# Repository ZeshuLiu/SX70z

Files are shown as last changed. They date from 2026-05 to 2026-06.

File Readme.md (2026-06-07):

# SX-70z

## 介绍
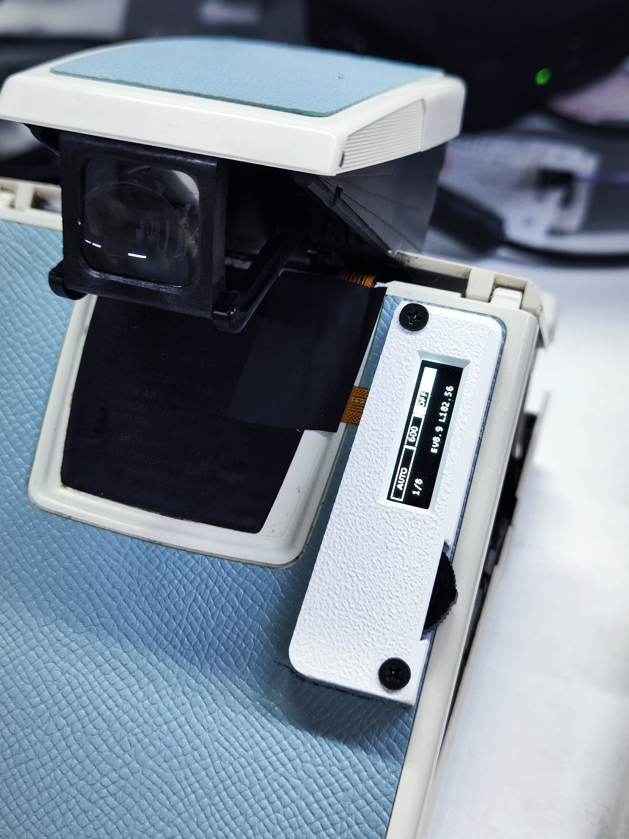
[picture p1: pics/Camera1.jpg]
机身照片


### 项目组成
项目中包含几个部分的硬件：

1. [相机主控板](Hardware/MainController)：替换相机机头内原装的控制器，接管相机的控制。
2. [机身控制器](Hardware/Body_controller)：显示当前相机工作状态并提供用于交互的按键。粘贴在机身背部，不会增加相机高度，因此大部分相机包依旧可以通用，与相机主控板连接需要 Fpc 排线。

### 开发

PCB部分除FPC使用嘉立创EDA外均使用KiCad9绘制，仓库提供了相应的工程和光绘(gerber)文件。

机身控制器采用ESP-IDF进行开发

## 性能参数
相机主控可以单独使用，此时可以进行自动测光和曝光，如果需要使用B、T以及手动模式需要配备机身控制器。

**快门速度：** 3s-1/8000s，共 27 档，支持 B 门及 T 门 。 T 门可设置时间，至多5h （非定时T和B门无时间限制）\
**自拍定时：** 0s/2s/5s/10s （倒计时完成后按当前模式自动曝光，倒计时期间挂起其余 Core 1 任务，不受按键干扰）\
**多重曝光：** 最多 11 张（受 MCU 机能限制，曝光过程中无法折叠相机，断电将导致快门保持打开状态造成严重过曝）。多重曝光期间电磁铁持续通电，间隔超过 5 分钟可能导致过热，建议尽快完成所有曝光并吐片。设置方式：长按进入设置菜单，切换 MultiExp 选项（-1 为仅中止/首张防护，0 为正常拍摄，1-10 为额外曝光张数）\
**测光：** 支持 ISO 640 相纸（通过 OPT4001 环境光传感器 + 窗口衰减系数 `METERING_ATTEN_K` 标定），实测与 **Sekonic L-308S** 测光表对比，全快门速度范围（3s – 1/8000s）精度一致，自动测光下最低快门速度 3s  \
**闪光同步：** 插入闪光灯后快门速度自动锁定 1/30s，手动模式可设置慢于 1/30s 进行填充闪光

*SX70的光圈在使用闪光灯时将会根据对焦距离进行收缩，此时调整黑白轮可以控制其光圈大小。本项目依旧保留了该特点，因此在使用闪光灯时请注意对焦距离以及黑白轮的位置*

### 曝光模式 × 闪光灯 行为矩阵

| 模式 | 无闪光灯 | 有闪光灯 |
|---|---|---|
| **AUTO** | 测光 → 自动选快门速度 → 普通曝光 | 快门固定 1/30s → 闪光曝光（47ms 预延迟后触发电容引闪） |
| **BULB** | 开快门 → 等 S1T 释放 → 关快门 | SOL2 光圈打开 → 开快门 → 47ms → 闪光 → 等 S1T 释放 |
| **TIME** | 开快门 → 等 S1T 按两次 → 关快门 | SOL2 光圈打开 → 开快门 → 47ms → 闪光 → 等 S1T 按两次 |
| **MANUAL** | 用户指定快门速度 → 普通曝光 | 快门限制在 1/30s，按用户速度计算 gap → 闪光曝光 |

所有模式下，相机任务均运行在 **ESP32 的 Core 1**，按优先级分层隔离，曝光时序不受 WiFi/BLE 干扰。

### 软件架构

```
Core 0:   WiFi 协议栈 + NimBLE BLE + HTTP Server (OTA Web) + 事件回调
Core 1:   相机控制（与射频中断隔离）
  ├─ Shutter  Task  prio 10 — 强时序引脚控制（busy-wait，独占 Core 1）
  ├─ Control  Task  prio 8  — 主控逻辑（按键/模式/S1 快门）
  ├─ Display  Task  prio 5  — SSD1306 I2C 刷屏（200ms 周期）
  └─ Metering Task  prio 3  — OPT4001 测光（1s 周期）
```

模块文件：

| 文件 | 职责 |
|---|---|
| `camera_main.c` | 任务调度、曝光时序、电磁铁/电机控制 |
| `gpio_inputs.c` | GPIO 输入处理：S1/S2 去抖、3D 按键、设置菜单（自拍定时 / 多重曝光 / IP 显示） |
| `display_manager.c` | OLED 帧绘制、倒计时显示、设置菜单布局 |
| `opt4001.c` | OPT4001 环境光传感器 I2C 驱动 |
| `ssd1306.c` | SSD1306 OLED I2C 驱动（esp_lcd 后端，含 `ssd1306_draw_str_black` 反色绘制） |
| `pcf8575.c` | PCF8575 I2C GPIO 扩展驱动 |
| `pin_init.c` | GPIO 引脚初始化 |
| `ota_web.c` | WiFi HTTP OTA 网页升级 |

### 设置菜单

长按 3D 按键的"按下"键进入设置菜单，菜单参数化支持上下键切换选项、短按"按下"键切换调整/浏览模式：

| 选项 | 说明 |
|---|---|
| **SelfTimer** | 自拍定时：0s / 2s / 5s / 10s |
| **MultiExp** | 多重曝光：-1（仅中止，首张防护）/ 0（正常）/ 1-10（额外张数，最多 11 张）|
| **IP Addr** | 只读，显示相机当前 WiFi IP 地址（未连接时显示 "not connected"）|

状态栏右上角同时显示当前自拍定时值与多重曝光剩余张数。

## 样片

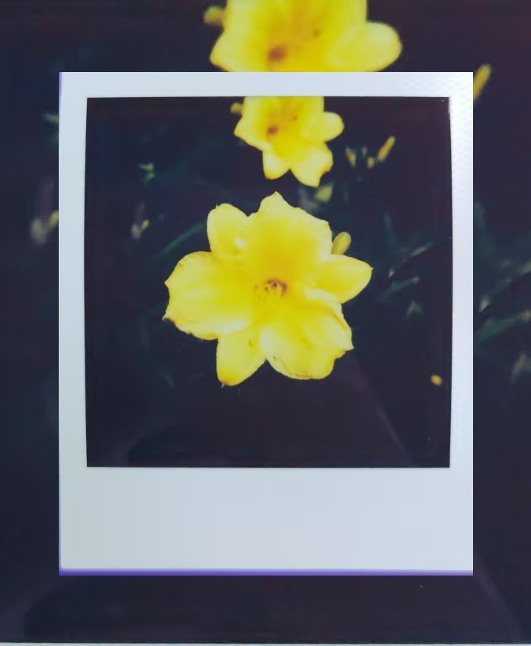
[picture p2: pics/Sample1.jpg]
样片1

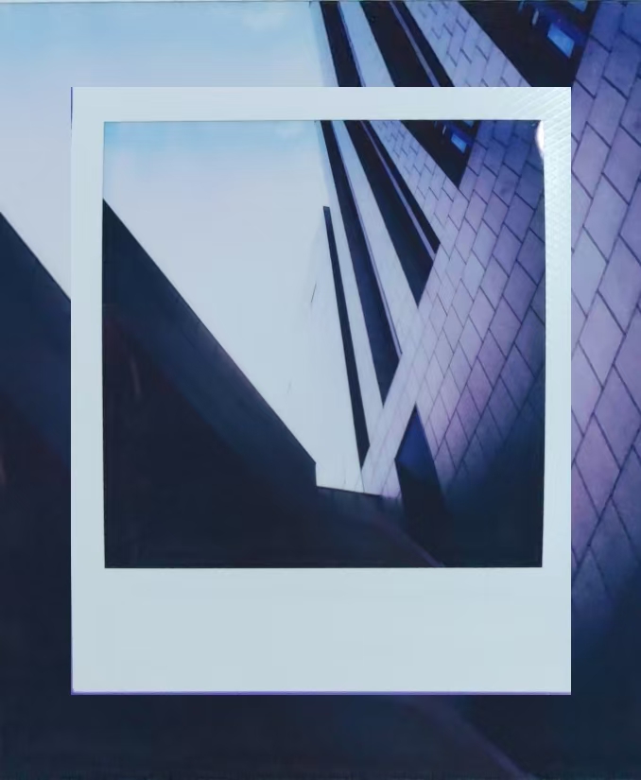
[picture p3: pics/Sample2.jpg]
样片2

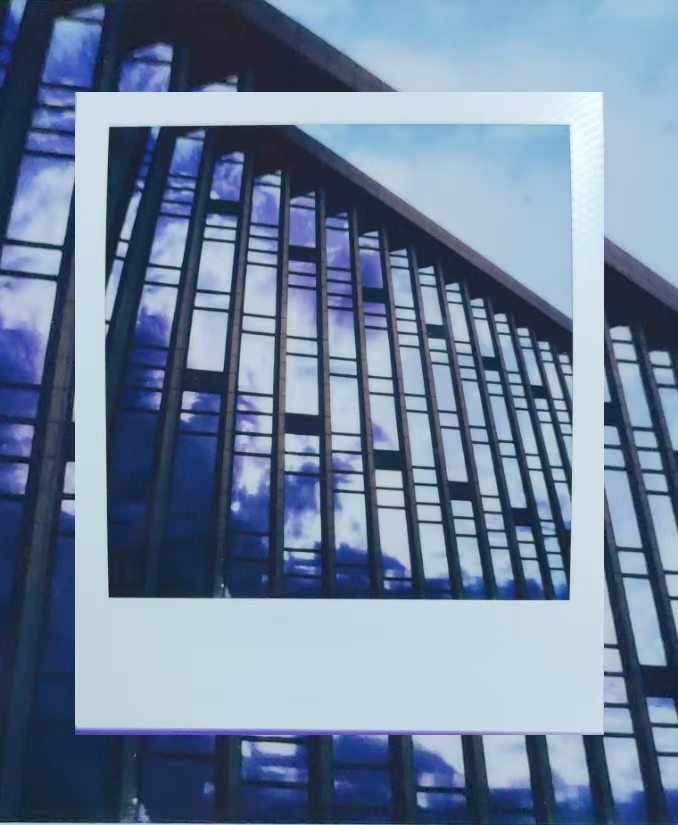
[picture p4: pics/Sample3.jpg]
样片3

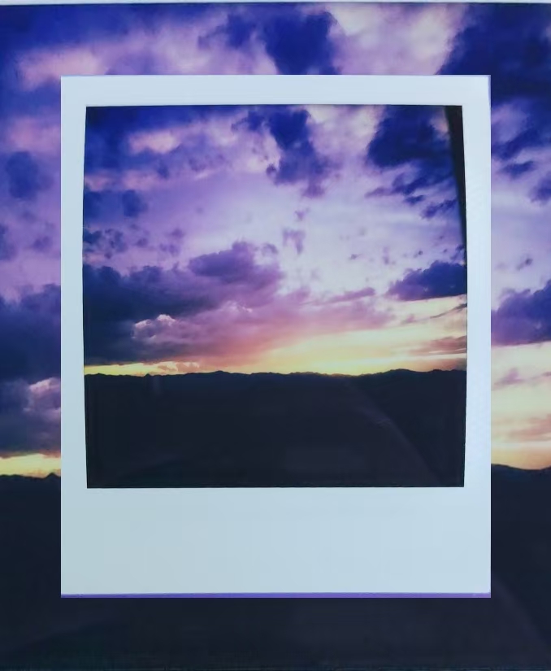
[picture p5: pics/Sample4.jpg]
样片4


## 硬件制造
光绘（Gerber）文件可以在 [Hardware](Hardware/) 目录下各子目录中找到，必须使用 0.8mm 以下的 PCB 制造。需要使用 fpc 软排线连接主板和机身控制器。

## 软件

在将机身主控安装至机器内部之前需要将固件通过串口烧录至控制器中。后续可以通过 OTA 无线升级，无需拆机。

**首次 WiFi 配网：**

首次开机相机没有 WiFi 凭据，会通过 BLE 广播 `SX70z_POP`。手机下载 **ESP BLE Provisioning** 应用（iOS/Android 应用商店均有），打开后选择配网，输入配对密钥 `sx70z123`，选择家中 WiFi 并输入密码即可。配网成功后凭据会存入 NVS，下次开机自动连接。

**OTA 升级方式：**
1. 相机开机连接 WiFi（通过 BLE 配网或已保存的凭据自动连接）
2. 手机或电脑连接同一局域网，浏览器打开 `http://SX70z` 或相机 IP
3. 选择编译好的 `.bin` 固件文件上传
4. 上传完成自动重启，新固件生效（Bootloader 会校验固件有效性，异常自动回滚）

建议针对自己的快门适当调整代码中 `shutter_times_x10[]` 的值，可以使用这个[快门速度测试器](https://github.com/ZeshuLiu/ShutterSpeedCalibrator)来测试机器的快门速度，便于调整。

## 组装
> 提示：组装需要一些基本的工具：电烙铁、撬棒和镊子。 \
大多数sx70相机的螺丝都是非常特殊的1mm x 1mm 宝丽来螺丝，拆卸需要特殊的螺丝刀，可以从咸鱼买一把或者自己磨一个。 \
在操作之前推荐先浏览以下内容[Disassembly Guide](https://instantphotography.files.wordpress.com/2010/12/polaroid-sx-70-camera-repair-book.pdf) 或者 [SX70 camera 125ASA to 600ASA conversion](https://opensx70.com/tutorials/100-600-conversion/).

拆卸后对原本主板进行替换即可，如需要机身控制器则将左上角焊盘焊线引出即可通过转接板连接机身控制器。焊接FPC时建议使用含铅(低温)焊锡，否则有损伤机器FPC的风险。只需要将原本的拆掉并且替换上去即可，对于有焊接及机身拆装经验的人来说难度不高。

### 相关开源软件

1. 项目受到了[OPSX ](https://github.com/sunyitong/OPSX)和[openSX70](https://github.com/openSX70)的启发。

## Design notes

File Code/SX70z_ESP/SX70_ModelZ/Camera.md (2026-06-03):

# Camera 工作模式与曝光流程

## 菜单模式

| `menu` | 模式 | `cam_mode` 显示 | `shut_mode` | 快门速度来源 |
|---|---|---|---|---|
| 0 | AUTO | `"AUTO"` | `'1'` | 测光自动计算 (`auto_shutter_pos`) |
| 1 | BULB (B) | `"B"` | `'B'` | 忽略，S1T 释放结束曝光 |
| 2 | TIME (T) | `"T"` | `'T'` | 忽略，S1T 按两次结束曝光 |
| 3 | MANUAL (M) | 快门速度字符串 | `'1'` | 用户手动选择（上/下键） |
| 10 | SELF-TIMER | `"---"` | 不变 | 禁止拍摄（shutter_task 跳过） |

## 全局参数

```c
typedef struct {
    bool if_display;            // OLED 是否可用
    bool has_flash;             // 闪光灯是否接入（control_task 防抖检测）

    metering_state_t metering;  // 测光
    button_state_t button;      // 按键

    uint8_t menu;               // 菜单层级
    char cam_mode[8];           // 当前模式显示字符串
    char shut_mode;             // 快门模式：'1'=NORMAL, 'B'=BULB, 'T'=TIME
    uint8_t shutter_speed;      // 快门速度索引 (0-26)

    bool test_led_level;        // LED 测试电平
} camera_state_t;
```

### camera_state.shut_mode 语义变化

旧代码中 `shut_mode` 混合表示闪光/模式两种状态：

- `'0'` = 闪光灯曝光路径
- `'1'` = 普通曝光
- `'B'` = B 门
- `'T'` = T 门

新代码中 `shut_mode` **仅表示用户选择的拍摄模式**，闪光灯作为独立 `has_flash` 布尔值传递：

- `'1'` = NORMAL 曝光（AUTO 和 MANUAL 共用）
- `'B'` = B 门
- `'T'` = T 门

`shutter_task` 内通过 `use_flash = camera_state.has_flash` 判断是否执行闪光相关步骤。

## 行为矩阵

| 模式 | 无闪光灯 | 有闪光灯 |
|---|---|---|
| **AUTO** | 测光 → `auto_shutter_pos` → `mode='1'` 普通曝光 | 快门固定 index 13 (1/30s) → `mode='1'` + `use_flash` → 闪光曝光 |
| **BULB** | `mode='B'` → 开快门 → 15ms → 等 S1T 释放 → 关快门 | `mode='B'` + `use_flash` → 开快门 → 15ms+32ms → **触发闪光** → 等 S1T 释放 → 关快门 |
| **TIME** | `mode='T'` → 开快门 → 等 S1T 释放 → 等再次按下 → 关快门 | `mode='T'` + `use_flash` → 开快门 → 47ms → **触发闪光** → 等 S1T 释放 → 等再次按下 → 关快门 |
| **MANUAL** | `mode='1'` → 用户指定快门速度 → 普通曝光 | `mode='1'` + `use_flash` → 按用户速度计算 gap → 闪光曝光 |
| **SELF-TIMER** | shutter_task 跳过（不拍摄） | shutter_task 跳过（不拍摄） |

## shutter_task 曝光时序

```
shutter_task (prio 10) — 由 xTaskNotifyGive 触发，执行完后回到阻塞态

  ┌─ 1. 关闭快门 ───────────────────────────────────────┐
  │    SOL1 100% 吸合 (30ms) → 40% 保持                  │
  ├─ 2. 电机启动，反光板上升 ──────────────────────────────┤
  │    电机转 → 等 S3 变高（反光板就位）→ 电机停           │
  ├─ 3. Y Delay ─────────────────────────────────────────┤
  │    if has_flash: SOL2 吸合（光圈打开）                 │
  │    固定 18ms Y 延时                                   │
  ├─ 4. 曝光（按 mode 分支） ──────────────────────────────┤
  │    mode='1' + 无闪光: 开快门 → gap 延时 → [步骤5关]   │
  │    mode='1' + 有闪光: 开快门 → 47ms → FF→1ms → gap   │
  │    mode='B':         开快门 → 15ms → [闪光] → 等释放  │
  │    mode='T':         开快门 → [闪光] → 等释放→等再按   │
  ├─ 5. 关闭快门 ────────────────────────────────────────┤
  │    SOL1 100% 吸合 (30ms) → 40% 保持 (18ms)           │
  ├─ 6. 光圈归位 ────────────────────────────────────────┤
  │    if has_flash: SOL2 断开                           │
  ├─ 7. 电机启动吐片 ─────────────────────────────────────┤
  │    电机转 → 等 S5 变低（胶片到位）→ 电机停 → SOL1释放  │
  └─ 8. 等 S1T 释放（防连拍） ────────────────────────────┘
```

### 普通曝光 (mode='1', 无闪光)

```
sol1_release()                     // 快门打开
delay_us(shutter_delay × 100)     // 按快门速度表延时（单位 0.1ms）
↓ 进入步骤 5
sol1_pull() → 30ms → sol1_hold()  // 快门关闭
```

### 闪光灯曝光 (mode='1', 有闪光)

```
sol1_release()                     // 快门打开
delay_us(47000)                    // 47ms — 等待快门完全打开
FF_PIN = 1  →  1ms  →  FF_PIN = 0 // 触发闪光灯
delay_us(gap × 100)               // 剩余延时
↓ 进入步骤 5
sol1_pull() → 30ms → sol1_hold()  // 快门关闭
```

其中 `gap = max(shutter_delay_x10 - 470, 0)`，闪光同步时总曝光时间 = 47ms + 1ms + gap。

### B 门 + 闪光

```
sol1_release()                     // 快门打开
delay_us(15000)                    // 15ms 稳定
delay_us(32000)                    // 额外 32ms，累计 47ms 后
FF_PIN = 1  →  1ms  →  FF_PIN = 0 // 触发闪光灯
while (S1T 释放)                   // 用户控制曝光时间
↓ 进入步骤 5 关快门
```

### T 门 + 闪光

```
sol1_release()                     // 快门打开
delay_us(47000)                    // 47ms
FF_PIN = 1  →  1ms  →  FF_PIN = 0 // 触发闪光灯
while (S1T 释放)                   // 第一次按下结束
while (S1T 再次按下)               // 第二次按下结束曝光
↓ 进入步骤 5 关快门
```

## 闪光灯检测

`control_task` 主循环中每 30ms 执行一次 S2 引脚防抖检测：

```c
// 闪光灯检测（带防抖）
static int flash_debounce = 0;
bool flash_level = (gpio_get_level(S2_PIN) == 0);
if (flash_level) {
    flash_debounce = min(flash_debounce + 1, 10);
} else {
    flash_debounce = max(flash_debounce - 1, 0);
}
camera_state.has_flash = (flash_debounce >= 8);
```

- S2 拉低 = 闪光灯接入
- 防抖阈值：连续检测到 8 次（~240ms）才确认有闪光灯
- 释放阈值：连续 2 次（~60ms 未检测到）开始递减

AUTO 模式下检测到闪光灯时，`shutter_speed` 被固定为 index 13（1/30s）：

```c
if (camera_state.menu == 0) {
    camera_state.shutter_speed = camera_state.metering.auto_shutter_pos;
    if (camera_state.has_flash) {
        camera_state.shutter_speed = 13;  // 1/30s
    }
}
```

## 快门速度表

27 档，索引 0~26：

| 索引 | 快门 | 标称 t(s) | EV | 阈值 EV | `shutter_times_x10` (0.1ms) |
|---|---|---|-----|---|---|
| 0 | 3s | 3.0 | 4.42 | ≤4.55 | 30000 |
| 1 | 2.5s | 2.5 | 4.68 | ≤4.84 | 25000 |
| 2 | 2s | 2.0 | 5.00 | ≤5.21 | 20000 |
| 3 | 1.5s | 1.5 | 5.42 | ≤5.71 | 15000 |
| 4 | 1s | 1.0 | 6.00 | ≤6.50 | 10500 |
| 5 | 1/2 | 0.5 | 7.00 | ≤7.29 | 5400 |
| 6 | 1/3 | 0.333 | 7.58 | ≤7.79 | 4700 |
| 7 | 1/4 | 0.25 | 8.00 | ≤8.29 | 3000 |
| 8 | 1/6 | 0.167 | 8.58 | ≤8.79 | 2900 |
| 9 | 1/8 | 0.125 | 9.00 | ≤9.16 | 1800 |
| 10 | 1/10 | 0.1 | 9.32 | ≤9.62 | 1450 |
| 11 | 1/15 | 0.0667 | 9.91 | ≤10.12 | 1060 |
| 12 | 1/20 | 0.05 | 10.32 | ≤10.62 | 880 |
| 13 | 1/30 | 0.0333 | 10.91 | ≤11.20 | 690 |
| 14 | 1/45 | 0.0222 | 11.49 | ≤11.70 | 610 |
| 15 | 1/60 | 0.0167 | 11.91 | ≤12.20 | 540 |
| 16 | 1/90 | 0.0111 | 12.49 | ≤12.73 | 500 |
| 17 | 1/125 | 0.008 | 12.96 | ≤13.23 | 450 |
| 18 | 1/180 | 0.00556 | 13.49 | ≤13.73 | 430 |
| 19 | 1/250 | 0.004 | 13.96 | ≤14.23 | 410 |
| 20 | 1/360 | 0.00278 | 14.49 | ≤14.73 | 370 |
| 21 | 1/500 | 0.002 | 14.96 | ≤15.46 | 340 |
| 22 | 1/1000 | 0.001 | 15.96 | ≤16.46 | 320 |
| 23 | 1/2000 | 0.0005 | 16.96 | ≤17.46 | 300 |
| 24 | 1/4000A | 0.00025 | 17.96 | ≤18.46 | 280 |
| 25 | 1/4000B | 0.00025 | 17.96 | (手动) | 260 |
| 26 | 1/8000 | 0.000125 | 18.96 | —— | 240 |

- `shutter_times_x10` 是光学校准后的实际延时值，单位 0.1ms
- EV 基于 F/8 镜头：`EV = log₂(64 / t_nominal)`
- `calc_shutter_from_ev(ev)` 用阈值 EV 查表，返回索引

## OLED 显示布局

```
┌──────────────────────────────────────────────┐
│ SX70z          B        EV13.6 L430.12       │
│ 3s     OFF     FLASH                          │
├──────────────────────────────────────────────┤
│ 上排左: 快门速度大字    上排右: EV / LUX      │
│ 下排左: 闪光灯状态      下排中: 拍摄模式       │
│         (OFF/FLASH)          (AUTO/B/T/speed) │
└──────────────────────────────────────────────┘
```

- `has_flash=false` → 显示 `"OFF"`
- `has_flash=true`  → 显示 `"FLASH"`
- `cam_mode` 在 AUTO 模式实时反映测光结果
- `menu=3`(MANUAL) 时 `cam_mode` 显示当前选择的快门速度字符串

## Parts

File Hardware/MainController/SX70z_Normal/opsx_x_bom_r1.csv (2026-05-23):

ID | 指示符 | 封装 | 数量 | 名称 | 供应商和参考
1 | U4 | TMB6-1.55-3.8X2.6MM | 1 | OPTICAL-TSL2561T(6P-3.8X2.6MM)
2 | U2 | DBV0005A_N | 1 | TLV70430DBVR
3 | R35,R27,R26,R3 | R_0402_1005Metric_Pad0.72x0.64mm_HandSolder | 4 | 1k
4 | D6,D5 | D_0603_1608Metric_Pad1.05x0.95mm_HandSolder | 2 | LED
5 | R34 | R_0402_1005Metric_Pad0.72x0.64mm_HandSolder | 1 | 330
6 | Q3 | SOT-23 | 1 | Q_PMOS_GSD
7 | R33 | R_0402_1005Metric_Pad0.72x0.64mm_HandSolder | 1 | 2.7k
8 | R32 | R_0402_1005Metric_Pad0.72x0.64mm_HandSolder | 1 | 47k
9 | R31 | R_0402_1005Metric_Pad0.72x0.64mm_HandSolder | 1 | 5.6k
10 | Q4 | SOT-23 | 1 | MMBT3904
11 | Z3,Z2,Z1 | Selector_default | 3 | ~
12 | R30 | R_0402_1005Metric_Pad0.72x0.64mm_HandSolder | 1 | 150
13 | R29 | R_0402_1005Metric_Pad0.72x0.64mm_HandSolder | 1 | 180
14 | C15 | C_0402_1005Metric_Pad0.74x0.62mm_HandSolder | 1 | 13p
15 | U6,U5 | TSOT-23-5 | 2 | AD8603
16 | R28,R8,R25,R23 | R_0402_1005Metric_Pad0.72x0.64mm_HandSolder | 4 | 100k
17 | R7 | R_0805_2012Metric_Pad1.20x1.40mm_HandSolder | 1 | 22k
18 | R10,R16,R14,R18,R5,R20 | R_0402_1005Metric_Pad0.72x0.64mm_HandSolder | 6 | 12k
19 | C8,C14,C6,C2,C10,C12,C7,C1,C9,C11 | C_0402_1005Metric_Pad0.74x0.62mm_HandSolder | 10 | 100n
20 | R12,R15,R6,R19,R9,R17,R11,R4,R13 | R_0402_1005Metric_Pad0.72x0.64mm_HandSolder | 9 | 10k
21 | R1,R2 | R_0402_1005Metric_Pad0.72x0.64mm_HandSolder | 2 | 27.4
22 | Q2,Q1 | SOT-23 | 2 | Q_NMOS_GSD
23 | sx1 | sx70 | 1 | sx~
24 | J2,J1,J3 | PinHeader_1x02_P2.54mm_Vertical | 3 | Conn_01x02
25 | C4 | C_0402_1005Metric_Pad0.74x0.62mm_HandSolder | 1 | 0.1u
26 | Y1 | Resonator_SMD_Murata_CSTxExxV-3Pin_3.0x1.1mm | 1 | Crystal_GND2
27 | D4,D3,D1 | D_SOD-323 | 3 | 1N4148WS
28 | R24,R21,R22 | R_0402_1005Metric_Pad0.72x0.64mm_HandSolder | 3 | 100
29 | U3 | SOIC-8_5.23x5.23mm_P1.27mm | 1 | W25Q128JVS
30 | C3,C13,C5 | C_0402_1005Metric_Pad0.74x0.62mm_HandSolder | 3 | 1u
31 | U1 | RP2040-QFN-56 | 1 | RP2040
32 | D2 | Osram_SFH2430 | 1 | SFH2430

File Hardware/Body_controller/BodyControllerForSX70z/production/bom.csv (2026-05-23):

Designator | Footprint | Quantity | Value | LCSC Part #
C1, C10, C11, C12, C2, C5, C6 | 0603 | 7 | 1uF
C3 | 0603 | 1 | 2.2uF
C4 | 0603 | 1 | 4.7uF
C7 | 0603 | 1 | 1uF(4.7uF)
DISP1 | SSD1306_0.91_i2c | 1 | ~
J1 | FPC-0.5LX-12PH20 | 1 | FPC-0.5LX-12PH20
J2 | PinHeader_1x04_P2.54mm_Horizontal | 1 | Conn_01x04_Pin
R1 | 0603 | 1 | 390k
R11, R3, R4 | 0603 | 3 | 10k
R2 | 0603 | 1 | 4.7k
SW3 | Direction3 Pin5 | 1 | ~
U1 | SSOP-20_4.4x6.5mm_P0.65mm | 1 | PCF8574ATS

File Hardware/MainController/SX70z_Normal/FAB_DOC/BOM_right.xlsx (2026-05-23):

Comment | Designator | Footprint | 嘉立创元件编号
100nF | C1,C2,C4,C6,C7,C8,C9,C10,C11,C12,C14 | 0402_C | C307331
1uF | C3,C5,C13 | 0402_C | C52923
1N4148WS | D1,D3,D4 | D_SOD-323 | C2128
LED | D5 | 0603_D | C72041
LED | D6 | 0603_D | C72038
Q_NMOS_GSD | Q1,Q2 | SOT-23 | C23521
Q_PMOS_GSD | Q3 | SOT-23 | C8549
MMBT3904 | Q4 | SOT-23 | C20526
27.4Ω | R1,R2 | 0402_R | C102945
1kΩ | R26,R27 | 0402_R | C11702
10kΩ | R4,R6,R9,R11,R12,R13,R15,R17,R19 | 0402_R | C25744
12kΩ | R5,R10,R14,R16,R18,R20 | 0402_R | C25752
100kΩ | R8,R28 | 0402_R | C25741
120Ω | R21,R22,R24 | 0402_R | C25079
5.6kΩ | R31 | 0402_R | C25908
47kΩ | R32 | 0402_R | C25792
2.7kΩ | R33 | 0402_R | C352444
330Ω | R34 | 0402_R | C25104
RP2040 | U1 | LQFN-56(7x7) | C2040
TLV70430DBVR | U2 | SOT-23-5 | C133625
W25Q128JVS | U3 | SOIC-8_5.23x5.23mm_P1.27mm | C97521
Crystal_GND2 | Y1 | Resonator_SMD_Murata_CSTxExxV-3Pin_3.0x1.1mm | C91581
1kΩ | R3,R35 | 0402_R | C11702
100kΩ | R23,R25 | 0402_R | C25741

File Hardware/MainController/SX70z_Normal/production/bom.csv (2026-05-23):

Designator | Footprint | Quantity | Value | LCSC Part #
C1, C2, C3 | 402 | 3 | DNP
C15, C6 | 402 | 2 | 100n
C4, C5 | 402 | 2 | 1u
C7 | 402 | 1 | 10uf
D1, D3, D4 | D_SOD-323 | 3 | 1N4148WS
D5 | 603 | 1 | LED
J1, J3 | PinHeader_1x02_P2.54mm_Vertical | 2 | Conn_01x02
J2 | PinHeader_1x03_P2.54mm_Vertical | 1 | Conn_01x03_Socket
L1 | 402 | 1 | 0R
Q1, Q2 | SOT-23 | 2 | Q_NMOS_GSD
Q5 | SOT-23 | 1 | MMBT3904
Q6 | SOT-23 | 1 | Q_PMOS_GSD
R1, R4, R11, R12, R13, R17, R19, R2, R3, R5, R9 | 402 | 10 | 10k
R10, R14, R18, R20 | 402 | 4 | 12k
R21, R22, R24 | 402 | 3 | 120
R23, R25 | 402 | 2 | 100k
R26 | 402 | 1 | 2.7k
R34 | 402 | 2 | 330
R6 | 402 | 1 | 1k
R7 | 402 | 1 | 5.6k
R8 | 402 | 1 | 47k
SX1 | sx70_i2c | 1 | sx~
U1 | AN2051-245 | 1 | ~
U3 | SOT-23-5 | 1 | SPX3819M5-L-3-3
U4 | QFN-48-1EP_7x7mm_P0.5mm_EP5.1x5.1mm_ThermalVias | 1 | ESP32-PICO-D4
U5 | OPT4001-DTS0008A-MFG | 1 | OPT4001DTSR

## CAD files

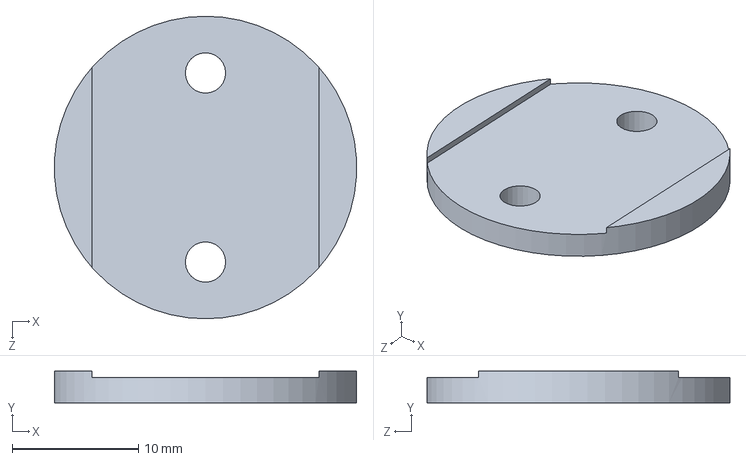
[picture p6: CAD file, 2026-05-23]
Hardware/TestBench/MainStandCover.SLDPRT
24.0 x 2.50 x 24.0 mm

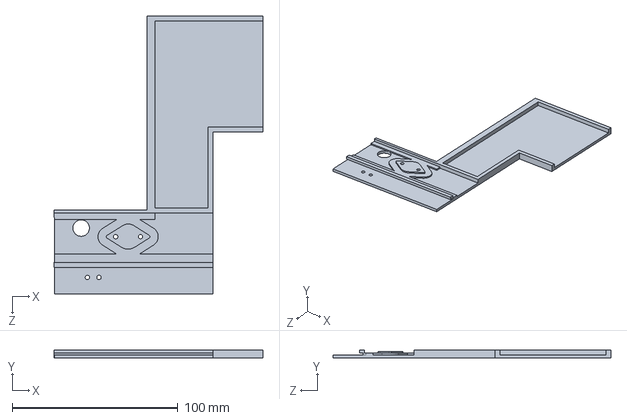
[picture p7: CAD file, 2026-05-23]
Hardware/TestBench/MainStand.SLDPRT
125.9 x 5.00 x 167.8 mm

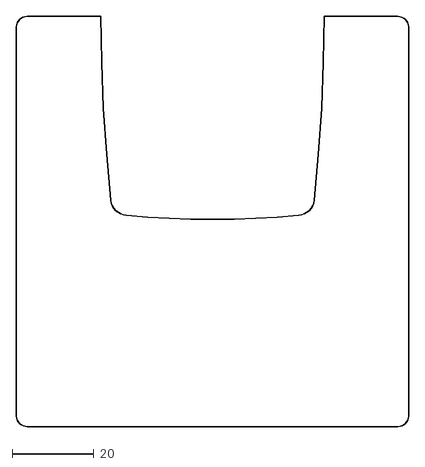
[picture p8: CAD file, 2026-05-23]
Hardware/Body_controller/BodyControllerForSX70z/sx-70-skin-back.dxf
96.1 x 100.6

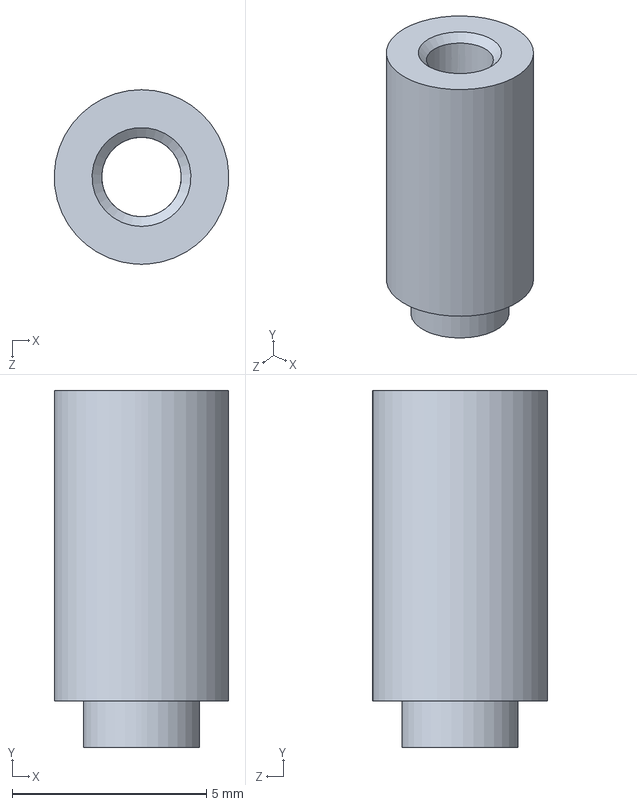
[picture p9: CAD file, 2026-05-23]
Hardware/Body_controller/Case/贴片螺母M2.5-H8-D3.SLDPRT
4.50 x 9.20 x 4.50 mm

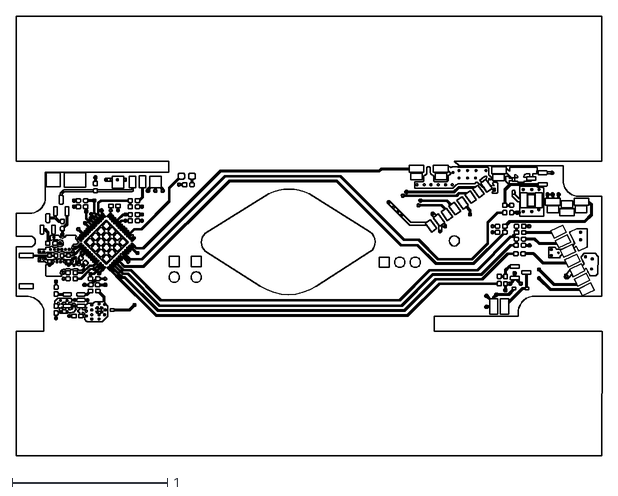
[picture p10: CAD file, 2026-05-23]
Hardware/MainController/SX70z_Normal/DXFs/SX70z_Normal-F_Cu.dxf
3.78 x 2.83

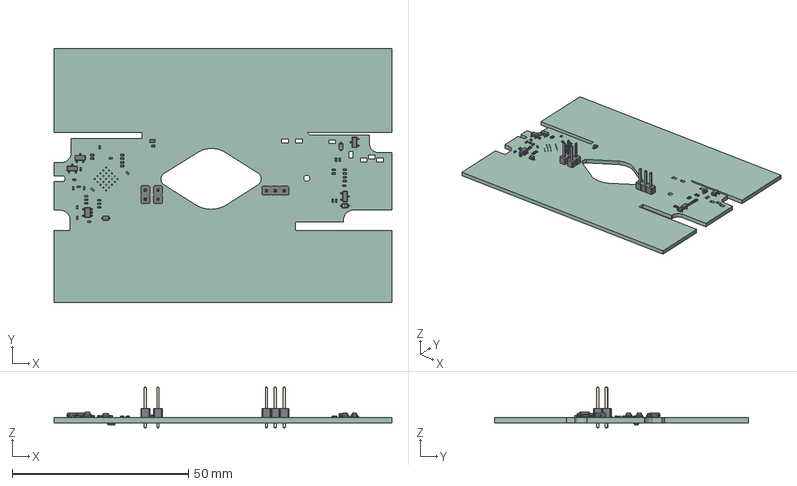
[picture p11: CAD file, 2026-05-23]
Hardware/MainController/SX70z_Normal/SX70z_Normal.step
95.9 x 72.0 x 11.5 mm
R_0402_1005Metric x 26
SOT-23 x 4
C_0402_1005Metric x 9
L_0402_1005Metric
D_SOD-323 x 3
D_0603_1608Metric
PinHeader_1x02_P2.54mm_Vertical x 2
PinHeader_1x03_P2.54mm_Vertical
SOT-23-5
FRAME
MOLD
SX70z_Normal_PCB

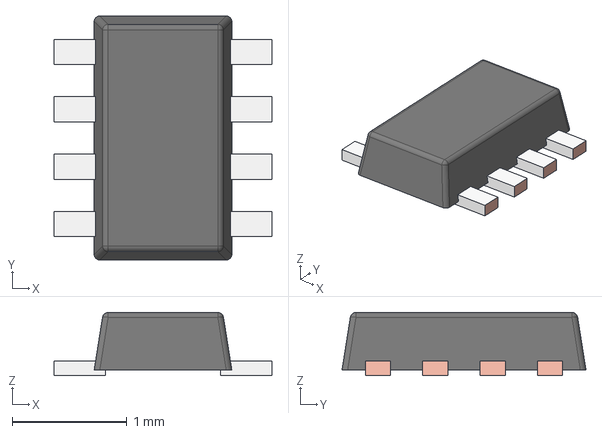
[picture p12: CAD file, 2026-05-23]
Hardware/MainController/SX70z_Normal/ul_OPT4001DTSR/OPT-4001-DTS0008A.stp
1.90 x 2.13 x 0.55 mm
FRAME
MOLD

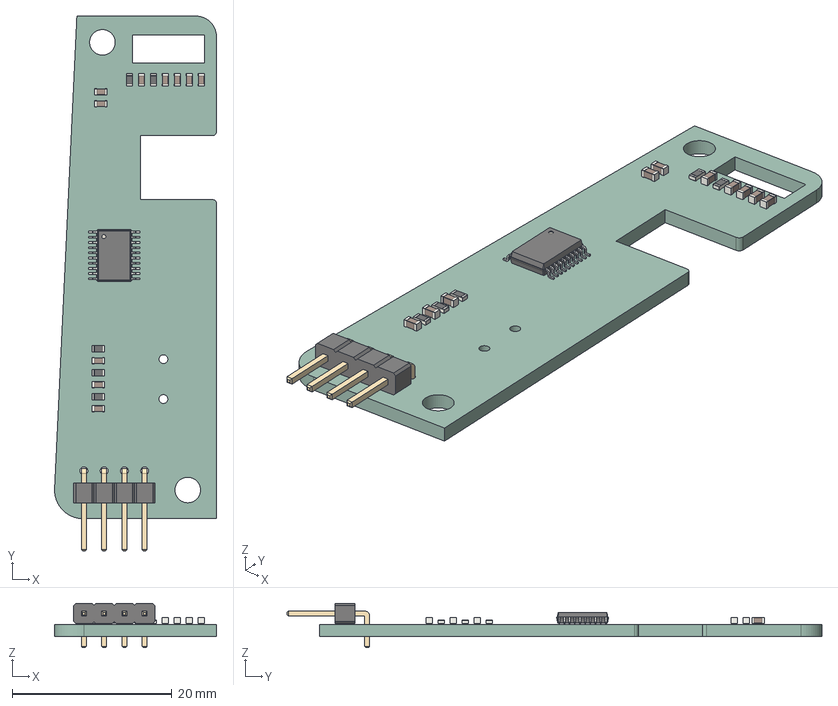
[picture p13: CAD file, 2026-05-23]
Hardware/Body_controller/BodyControllerForSX70z/BodyControllerForSX70z_R1_0.step
20.3 x 67.0 x 5.54 mm
C_0603_1608Metric x 10
R_0603_1608Metric x 5
PinHeader_1x04_P2.54mm_Horizontal
SSOP-20_4.4x6.5mm_P0.65mm
BodyControllerForSX70z_PCB

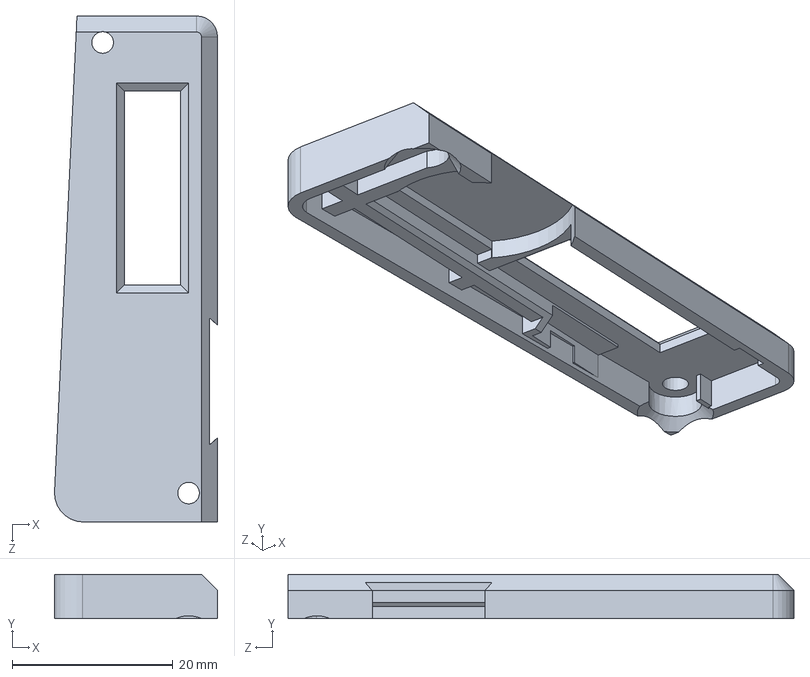
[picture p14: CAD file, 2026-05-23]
Hardware/Body_controller/Case/外壳.SLDPRT
20.3 x 5.50 x 63.0 mm

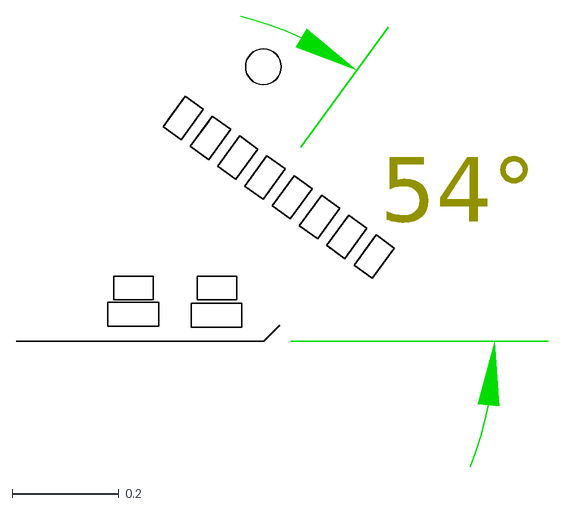
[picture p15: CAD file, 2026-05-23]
Hardware/MainController/SX70z_Normal/DXFs/SX70z_Normal_连接器部分外形.dxf
54°

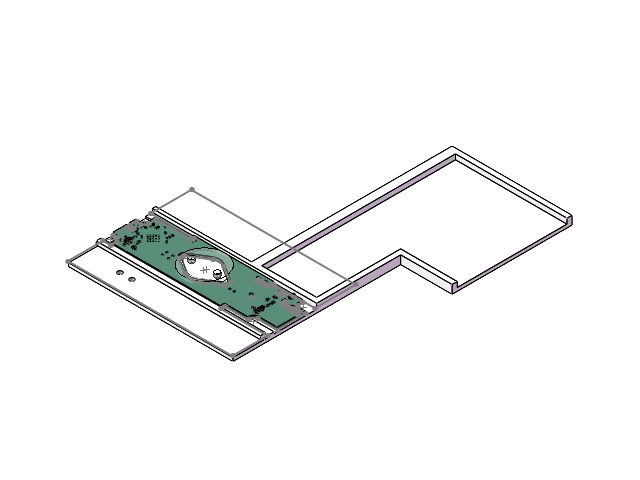
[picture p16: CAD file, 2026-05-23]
Hardware/TestBench/TestBench.SLDASM
MainStand
FRAME
MOLD
R_0402_1005Metric x 26
SOT-23 x 4
C_0402_1005Metric x 9
L_0402_1005Metric
D_SOD-323 x 3
D_0603_1608Metric
SOT-23-5
SX70z_Normal_PCB
MainStandCover

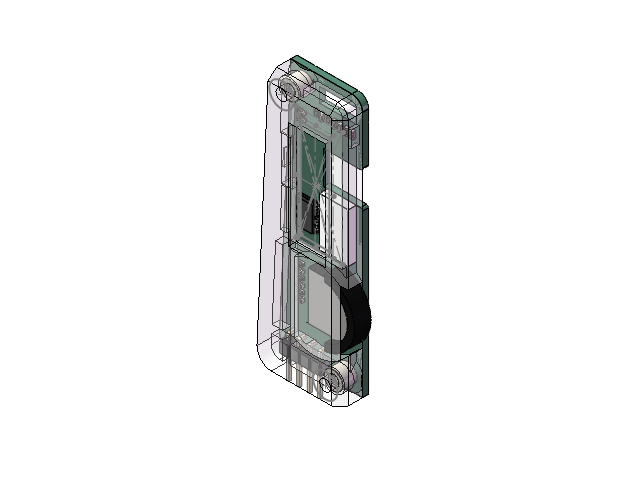
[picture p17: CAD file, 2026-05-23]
Hardware/Body_controller/Case/外壳装配.SLDASM
C_0603_1608Metric_2.step x 10
R_0603_1608Metric_2.step x 5
PinHeader_1x04_P2.54mm_Horizontal_2.step
SSOP-20_4.4x6.5mm_P0.65mm_2.step
BodyControllerForSX70z_PCB_2.step
贴片螺母M2.5-H3.5-D3 x 2
大头拨轮
外壳
垫片

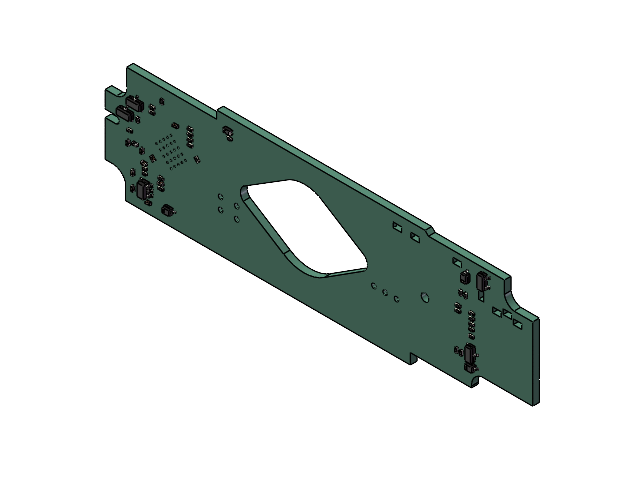
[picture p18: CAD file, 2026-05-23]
Hardware/TestBench/PCB/SX70z_Normal_R3_5.SLDASM
FRAME
MOLD
R_0402_1005Metric x 26
SOT-23 x 4
C_0402_1005Metric x 9
L_0402_1005Metric
D_SOD-323 x 3
D_0603_1608Metric
SOT-23-5
SX70z_Normal_PCB

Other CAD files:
Hardware/TestBench/PCB/SX70z_Normal.SLDASM
Hardware/TestBench/PCB/OPT-4001-DTS0008A.SLDASM
Hardware/Body_controller/ref/sx-70-skin-template-vector-v1.10-empty.dwg
Hardware/TestBench/PCB/SX70z_Normal_PCB.SLDPRT
Hardware/Body_controller/ref/sx-70-skin-sholder.dxf
Hardware/Body_controller/BodyControllerForSX70z/BodyControllerForSX70z_R1_1.step
Hardware/Body_controller/Case/BodyControllerForSX70z_R1_0.SLDASM
Hardware/Body_controller/Case/BodyControllerForSX70z_R1_1.SLDASM
Hardware/Body_controller/Case/BodyControllerForSX70z_R1_1.step
Hardware/Body_controller/Case/垫片.SLDPRT
Hardware/Body_controller/Case/垫片.STL
Hardware/Body_controller/Case/外壳.3mf
Hardware/Body_controller/Case/外壳.STL
Hardware/Body_controller/Case/大头拨轮.SLDPRT
Hardware/Body_controller/Case/贴片螺母M2.5-H3.5-D3.SLDPRT
Hardware/Body_controller/ref/sx-70-skin-sholder.dwg
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

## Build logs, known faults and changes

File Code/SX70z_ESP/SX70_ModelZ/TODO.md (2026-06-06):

# T、B门菜单合并
camera_state 加一个 uint16 TIME_MODE：0-B 1-T 然后再往上就是时间。统一归到menu 1里面去，通过上下键控制
然后这时候手动挡会变成menu 2

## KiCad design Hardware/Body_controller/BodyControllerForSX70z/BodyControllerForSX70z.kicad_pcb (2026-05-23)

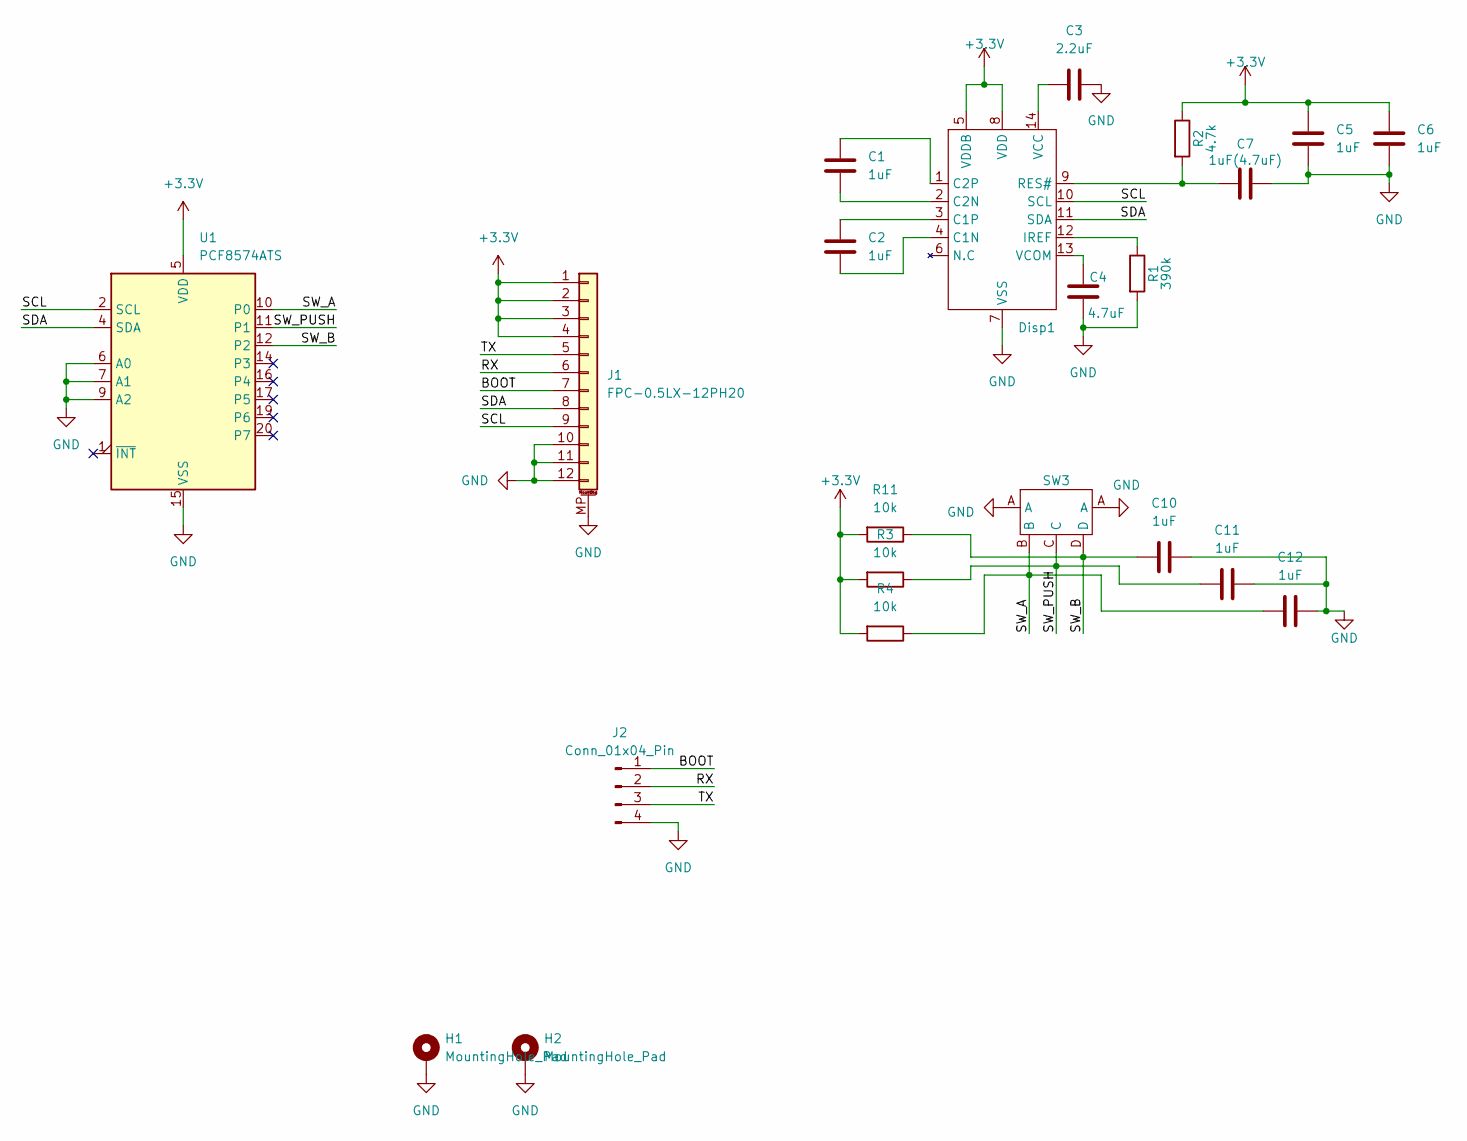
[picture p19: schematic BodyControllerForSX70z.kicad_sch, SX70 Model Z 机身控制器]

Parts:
C1, C2, C5, C6, C10, C11, C12: 1uF; C_0603_1608Metric_Pad1.08x0.95mm_HandSolder
C3: 2.2uF; C_0603_1608Metric_Pad1.08x0.95mm_HandSolder
C4: 4.7uF; C_0603_1608Metric_Pad1.08x0.95mm_HandSolder
C7: 1uF(4.7uF); C_0603_1608Metric_Pad1.08x0.95mm_HandSolder
Disp1: SSD1306_0.91_i2c
H1, H2: MountingHole_Pad; MountingHole_3.2mm_M3_DIN965_Pad
J1: FPC-0.5LX-12PH20
J2: Conn_01x04_Pin; PinHeader_1x04_P2.54mm_Horizontal
R1: 390k; R_0603_1608Metric_Pad0.98x0.95mm_HandSolder
R2: 4.7k; R_0603_1608Metric_Pad0.98x0.95mm_HandSolder
R3, R4, R11: 10k; R_0603_1608Metric_Pad0.98x0.95mm_HandSolder
SW3: Direction3 Pin5
U1: PCF8574ATS; SSOP-20_4.4x6.5mm_P0.65mm

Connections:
+3.3V: C5.1, C6.1, Disp1.5 (VDDB), Disp1.8 (VDD), J1.1, J1.2, J1.3, J1.4, R2.1, R3.2, R4.2, R11.2, U1.5 (VDD)
/BOOT: J1.7, J2.1
/RX: J1.6, J2.2
/SCL: Disp1.10 (SCL), J1.9, U1.2 (SCL)
/SDA: Disp1.11 (SDA), J1.8, U1.4 (SDA)
/SW_A: C12.1, R4.1, SW3.B, U1.10 (P0)
/SW_B: C10.1, R11.1, SW3.D, U1.12 (P2)
/SW_PUSH: C11.1, R3.1, SW3.C, U1.11 (P1)
/TX: J1.5, J2.3
GND: C3.2, C4.1, C5.2, C6.2, C7.2, C10.2, C11.2, C12.2, Disp1.7 (VSS), H1.1, H2.1, J1.10, J1.11, J1.12, J1.MP (MountPin), J2.4, R1.2, SW3.A, U1.6 (A0), U1.7 (A1), U1.9 (A2), U1.15 (VSS)
unnamed: C2.2, Disp1.4 (C1N)
unnamed: C2.1, Disp1.3 (C1P)
unnamed: C1.2, Disp1.2 (C2N)
unnamed: C1.1, Disp1.1 (C2P)
unnamed: Disp1.12 (IREF), R1.1
unnamed: C7.1, Disp1.9 (RES#), R2.2
unnamed: C3.1, Disp1.14 (VCC)
unnamed: C4.2, Disp1.13 (VCOM)

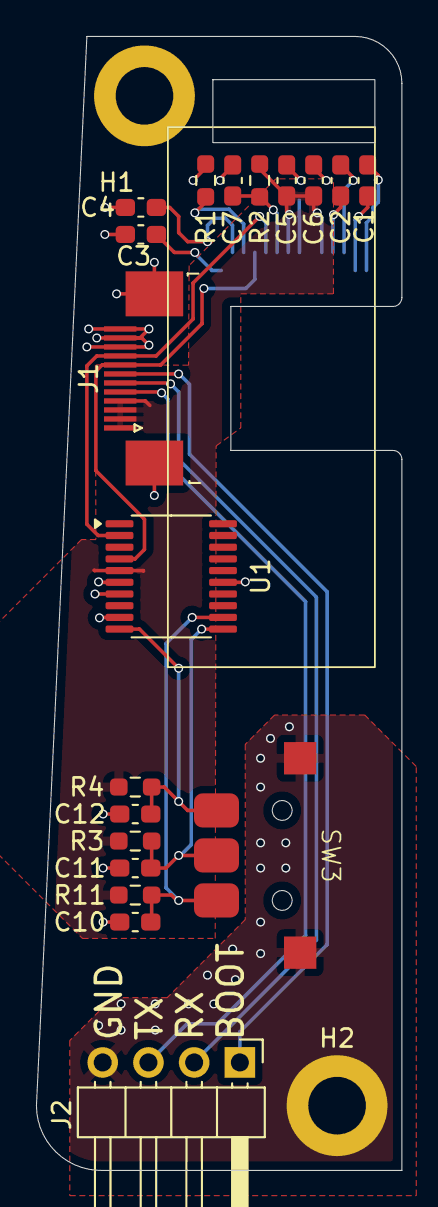
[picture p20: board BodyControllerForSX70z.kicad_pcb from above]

Board: 2 copper layers, 20.3 x 63.0 mm, 22 parts (1 on the bottom side), 18 nets.

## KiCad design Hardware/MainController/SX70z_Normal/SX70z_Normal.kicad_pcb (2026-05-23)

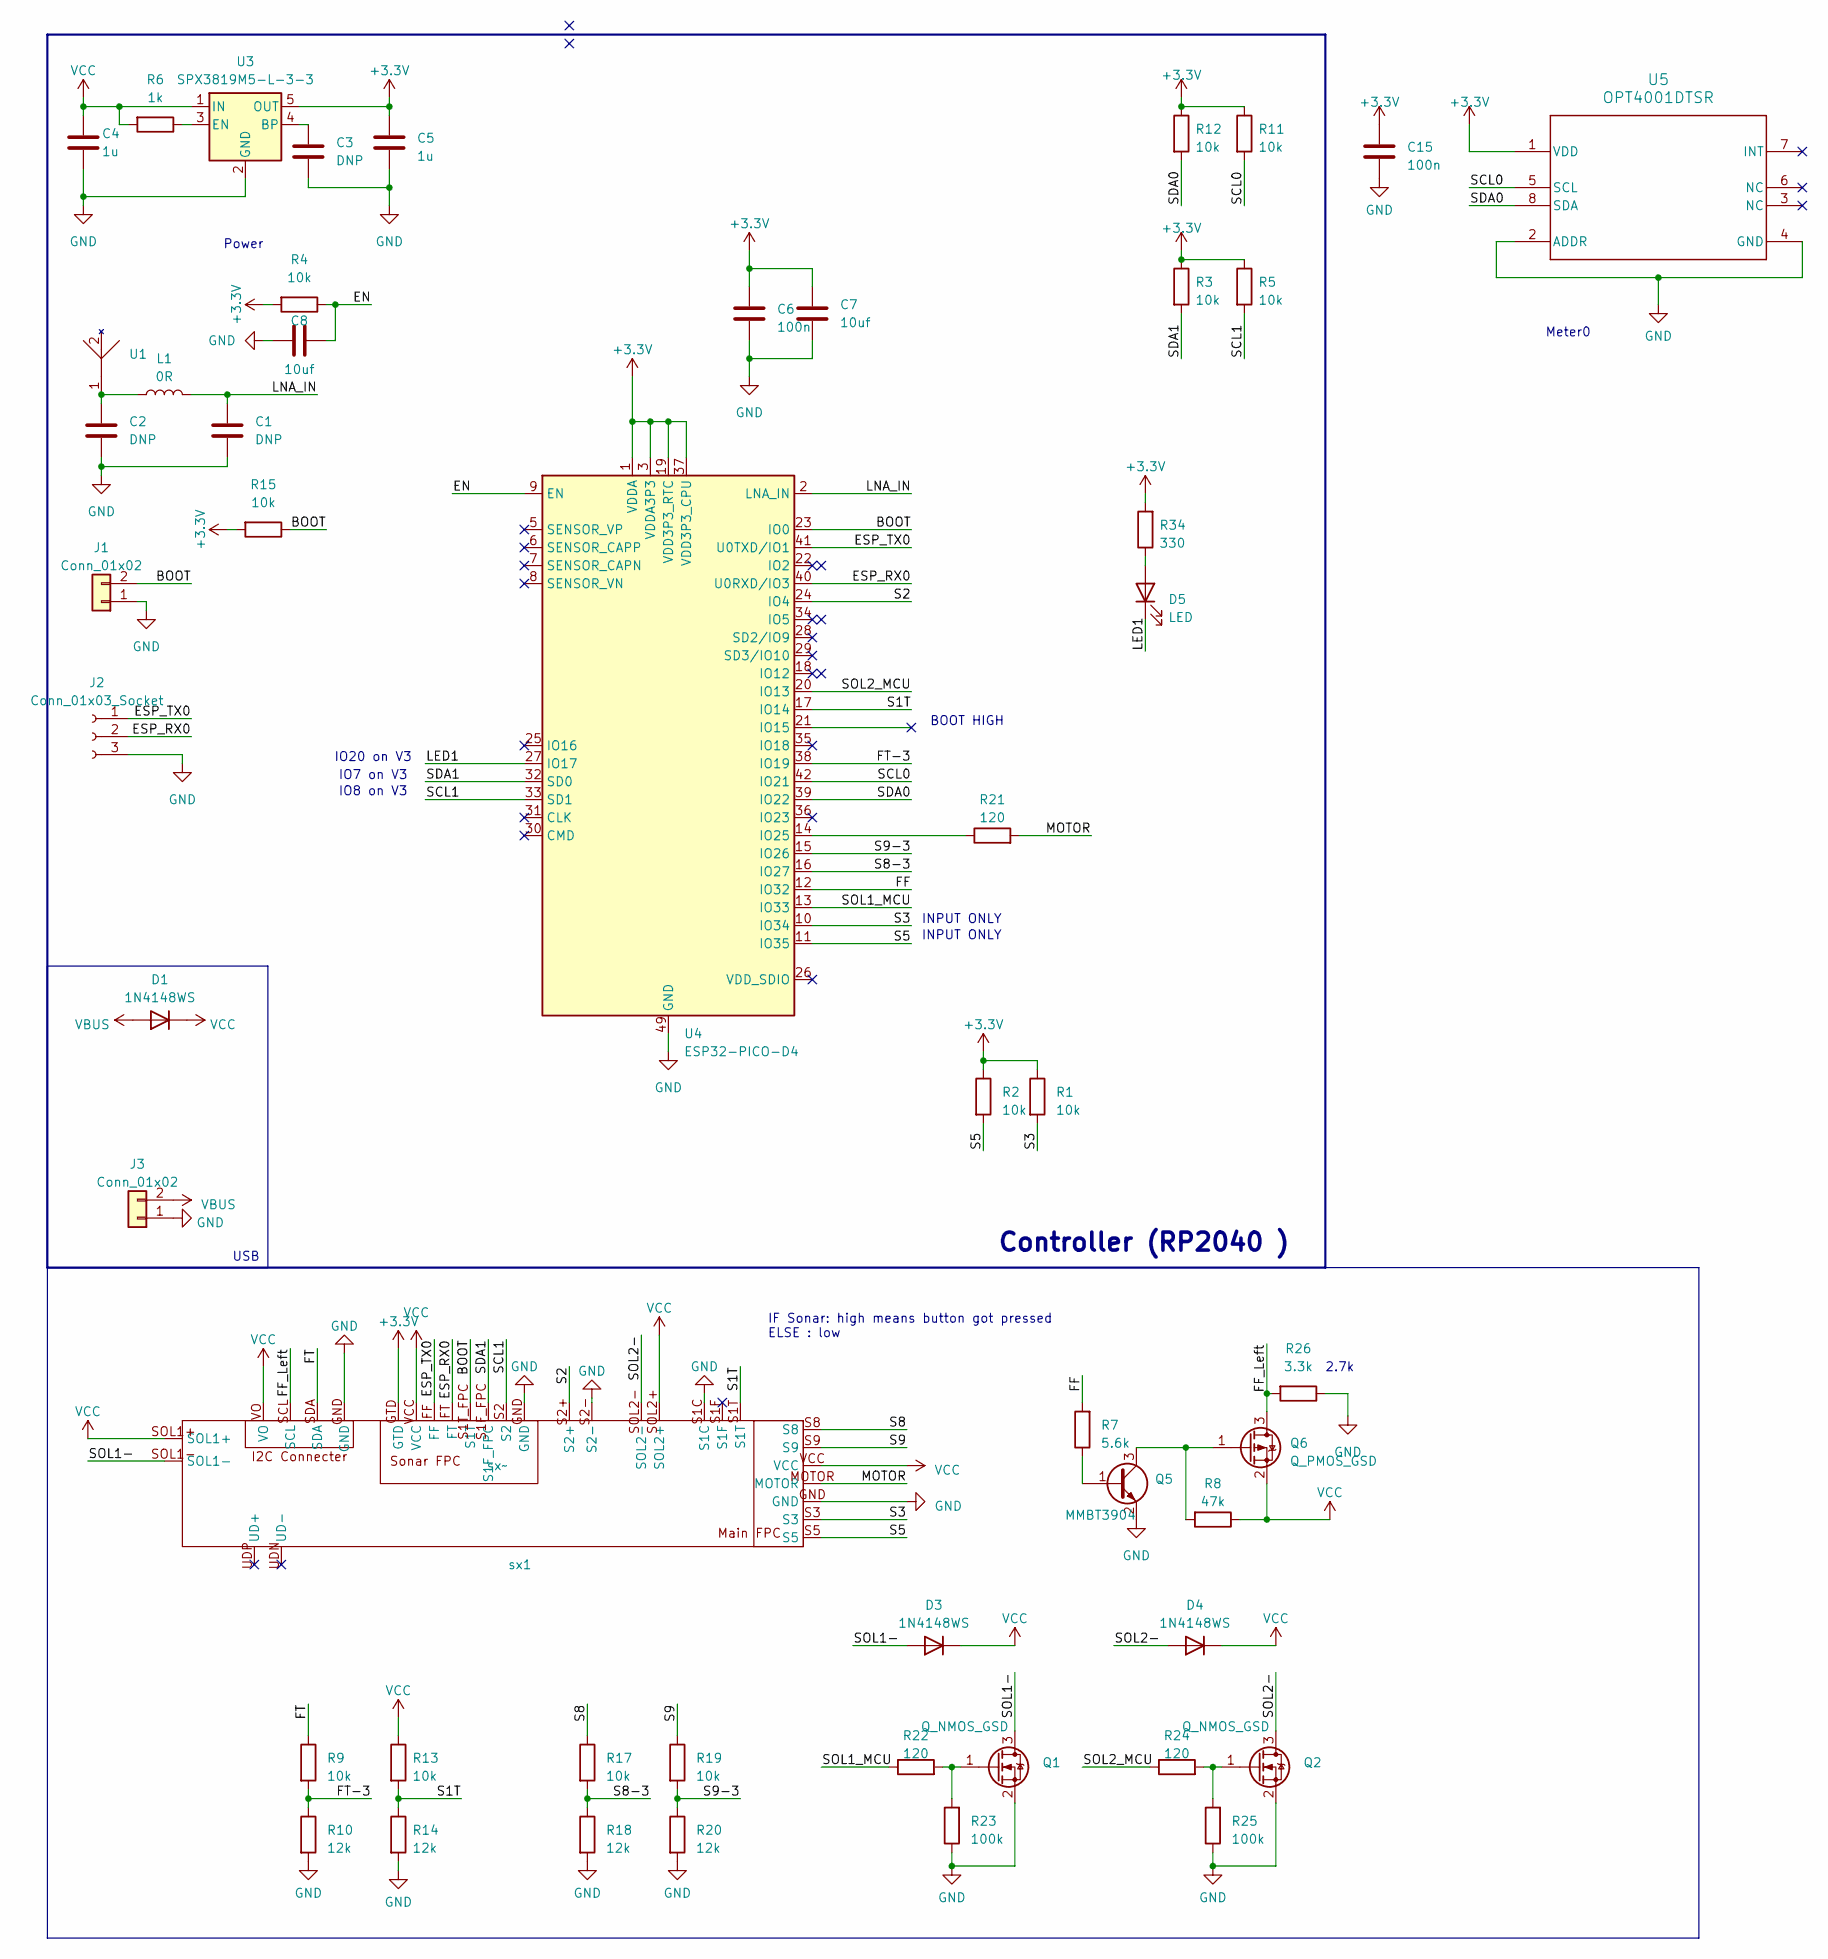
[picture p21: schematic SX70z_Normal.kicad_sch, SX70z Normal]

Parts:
C1, C2: DNP; C_0402_1005Metric
C3: DNP; C_0402_1005Metric_Pad0.74x0.62mm_HandSolder
C4, C5: 1u; C_0402_1005Metric_Pad0.74x0.62mm_HandSolder
C6, C15: 100n; C_0402_1005Metric_Pad0.74x0.62mm_HandSolder
C7: 10uf; C_0402_1005Metric_Pad0.74x0.62mm_HandSolder
C8: 10uf; C_0402_1005Metric
D1, D3, D4: 1N4148WS; D_SOD-323
D5: LED; D_0603_1608Metric_Pad1.05x0.95mm_HandSolder
J1, J3: Conn_01x02; PinHeader_1x02_P2.54mm_Vertical
J2: Conn_01x03_Socket; PinHeader_1x03_P2.54mm_Vertical
L1: 0R; L_0402_1005Metric
Q1, Q2: Q_NMOS_GSD; SOT-23
Q5: MMBT3904; SOT-23
Q6: Q_PMOS_GSD; SOT-23
R1, R2, R3, R4, R5, R9, R11, R12, R13, R15, R17, R19: 10k; R_0402_1005Metric_Pad0.72x0.64mm_HandSolder
R6: 1k; R_0402_1005Metric_Pad0.72x0.64mm_HandSolder
R7: 5.6k; R_0402_1005Metric_Pad0.72x0.64mm_HandSolder
R8: 47k; R_0402_1005Metric_Pad0.72x0.64mm_HandSolder
R10, R14, R18, R20: 12k; R_0402_1005Metric_Pad0.72x0.64mm_HandSolder
R21, R22, R24: 120; R_0402_1005Metric_Pad0.72x0.64mm_HandSolder
R23, R25: 100k; R_0402_1005Metric_Pad0.72x0.64mm_HandSolder
R26: 3.3k; R_0402_1005Metric_Pad0.72x0.64mm_HandSolder
R34: 330; R_0402_1005Metric_Pad0.72x0.64mm_HandSolder
U1: AN2051-245
U3: SPX3819M5-L-3-3; SOT-23-5
U4: ESP32-PICO-D4; QFN-48-1EP_7x7mm_P0.5mm_EP5.1x5.1mm_ThermalVias
U5: OPT4001DTSR; OPT4001-DTS0008A-MFG
sx1: sx~; sx70_i2c

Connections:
+3.3V: C5.1, C6.1, C7.1, C15.1, R1.1, R2.1, R3.1, R4.2, R5.1, R11.1, R12.1, R15.2, R34.2, U3.5 (OUT), U4.1 (VDDA), U4.3 (VDDA3P3), U4.4 (VDDA3P3), U4.19 (VDD3P3_RTC), U4.37 (VDD3P3_CPU), U4.43 (VDDA), U4.46 (VDDA), U5.1 (VDD), sx1.GTD
/BOOT: J1.2, R15.1, U4.23 (IO0), sx1.S1T_FPC (S1T)
/EN: C8.2, R4.1, U4.9 (EN)
/ESP_RX0: J2.2, U4.40 (U0RXD/IO3), sx1.FT
/ESP_TX0: J2.1, U4.41 (U0TXD/IO1), sx1.FF
/FF: R7.2, U4.12 (IO32)
/FF_Left: Q6.3 (D), R26.2, sx1.SCL
/FT: R9.1, sx1.SDA
/FT-3: R9.2, R10.1, U4.38 (IO19)
/LED1: D5.1 (K), U4.27 (IO17)
/LNA_IN: C1.1, L1.2, U4.2 (LNA_IN)
/MOTOR: R21.2, sx1.MOTOR
/S1T: R13.2, R14.1, U4.17 (IO14), sx1.S1T
/S2: U4.24 (IO4), sx1.S2+
/S3: R1.2, U4.10 (IO34), sx1.S3
/S5: R2.2, U4.11 (IO35), sx1.S5
/S8: R17.1, sx1.S8
/S8-3: R17.2, R18.1, U4.16 (IO27)
/S9: R19.1, sx1.S9
/S9-3: R19.2, R20.1, U4.15 (IO26)
/SCL0: R11.2, U4.42 (IO21), U5.5 (SCL)
/SCL1: R5.2, U4.33 (SD1), sx1.S2
/SDA0: R12.2, U4.39 (IO22), U5.8 (SDA)
/SDA1: R3.2, U4.32 (SD0), sx1.S1F_FPC
/SOL1-: D3.2 (A), Q1.3 (D), sx1.SOL1-
/SOL1_MCU: R22.1, U4.13 (IO33)
/SOL2-: D4.2 (A), Q2.3 (D), sx1.SOL2-
/SOL2_MCU: R24.1, U4.20 (IO13)
GND: C1.2, C2.2, C3.2, C4.2, C5.2, C6.2, C7.2, C8.1, C15.2, J1.1, J2.3, J3.1, Q1.2 (S), Q2.2 (S), Q5.2 (E), R10.2, R14.2, R18.2, R20.2, R23.1, R25.1, R26.1, U3.2 (GND), U4.49 (GND), U5.2 (ADDR), U5.4 (GND), sx1.GND, sx1.S1C, sx1.S2-
unnamed: C2.1, L1.1, U1.1
unnamed: D5.2 (A), R34.1
unnamed: Q1.1 (G), R22.2, R23.2
unnamed: Q2.1 (G), R24.2, R25.2
unnamed: Q5.1 (B), R7.1
unnamed: Q5.3 (C), Q6.1 (G), R8.2
unnamed: C3.1, U3.4 (BP)
unnamed: R6.1, U3.3 (EN)
unnamed: R21.1, U4.14 (IO25)
VBUS: D1.2 (A), J3.2
VCC: C4.1, D1.1 (K), D3.1 (K), D4.1 (K), Q6.2 (S), R6.2, R8.1, R13.1, U3.1 (IN), sx1.SOL1+, sx1.SOL2+, sx1.VCC, sx1.VO

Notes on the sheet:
Meter0
Power
2.7k
IF Sonar: high means button got pressed ELSE : low
Controller (RP2040 )
IO8 on V3
IO7 on V3
INPUT ONLY
BOOT HIGH
IO20 on V3
USB

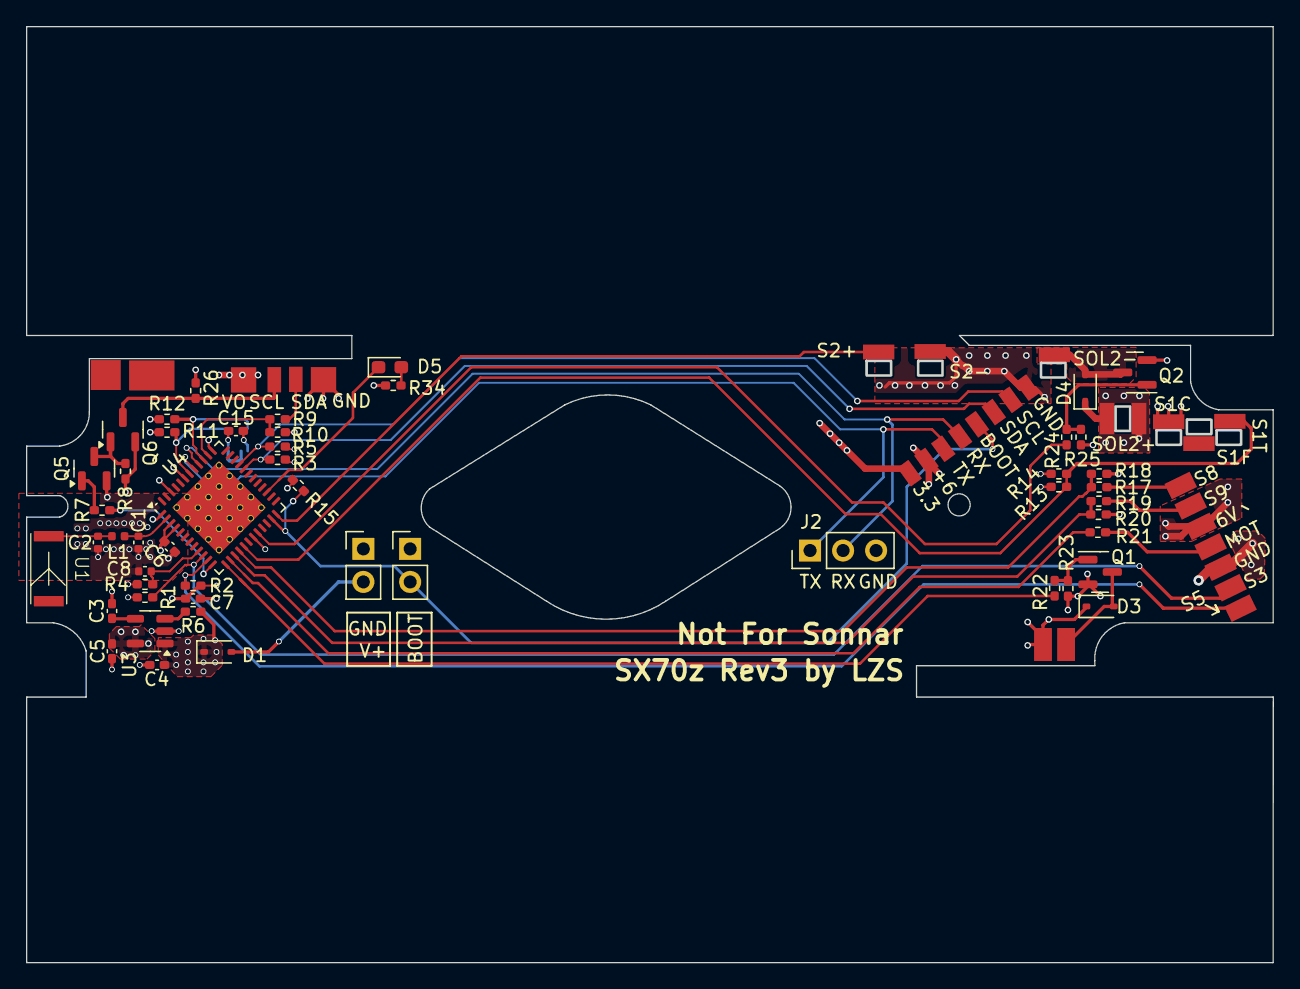
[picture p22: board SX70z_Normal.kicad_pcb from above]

Board: 4 copper layers, 95.9 x 72.0 mm, 52 parts (1 on the bottom side), 40 nets.

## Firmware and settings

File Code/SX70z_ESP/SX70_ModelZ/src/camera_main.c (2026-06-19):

/* camera_main.c - 相机主控：任务调度、曝光时序、快门/电磁铁控制 */

#include "camera_main.h"
#include "display_manager.h"
#include "gpio_inputs.h"
#include "fonts/font5x8.h"
#include "opt4001.h"
#include "ssd1306.h"
#include "pcf8575.h"
#include "PIN.h"
#include "esp_log.h"
#include "driver/gptimer.h"
#include "driver/gpio.h"
#include "esp_timer.h"
#include "driver/ledc.h"
#include "esp_task_wdt.h"
#include <string.h>
#include <math.h>

static const char *TAG = "camera";

TaskHandle_t control_task_handle = NULL;
static TaskHandle_t display_task_handle = NULL;
static TaskHandle_t metering_task_handle = NULL;

ssd1306_t display;
pcf8575_t gpio_expander;

static TaskHandle_t shutter_task_handle = NULL;

/* ---- us 级精确定时器（GPTimer one-shot alarm + ISR, Core 1 同核） ---- */
static volatile bool g_timer_done;
static gptimer_handle_t g_delay_timer;

static bool IRAM_ATTR delay_timer_cb(gptimer_handle_t timer,
                                      const gptimer_alarm_event_data_t *edata,
                                      void *user_ctx)
{
    g_timer_done = true;
    return false;
}

static gptimer_alarm_config_t g_alarm_cfg = {
    .alarm_count = 0,
    .reload_count = 0,
    .flags.auto_reload_on_alarm = false,
};

void delay_us(uint32_t us)
{
    gptimer_stop(g_delay_timer);
    gptimer_set_raw_count(g_delay_timer, 0);
    g_alarm_cfg.alarm_count = us;
    gptimer_set_alarm_action(g_delay_timer, &g_alarm_cfg);
    g_timer_done = false;
    gptimer_start(g_delay_timer);
    while (!g_timer_done) {
        __asm__("nop");
    }
}

/* ---- LEDC PWM 电磁铁控制（100% 吸合 / 40% 保持） ---- */

static void sol1_pull(void)
{
    ledc_set_duty(LEDC_HIGH_SPEED_MODE, LEDC_CHANNEL_0, SOL1_DUTY_FULL);
    ledc_update_duty(LEDC_HIGH_SPEED_MODE, LEDC_CHANNEL_0);
}

static void sol1_hold(void)
{
    ledc_set_duty(LEDC_HIGH_SPEED_MODE, LEDC_CHANNEL_0, SOL1_DUTY_HOLD);
    ledc_update_duty(LEDC_HIGH_SPEED_MODE, LEDC_CHANNEL_0);
}

static void sol1_release(void)
{
    ledc_set_duty(LEDC_HIGH_SPEED_MODE, LEDC_CHANNEL_0, SOL2_DUTY_OFF);
    ledc_update_duty(LEDC_HIGH_SPEED_MODE, LEDC_CHANNEL_0);
}

static void sol2_engage(void)
{
    ledc_set_duty(LEDC_HIGH_SPEED_MODE, LEDC_CHANNEL_1, SOL2_DUTY_ON);
    ledc_update_duty(LEDC_HIGH_SPEED_MODE, LEDC_CHANNEL_1);
}

static void sol2_disengage(void)
{
    ledc_set_duty(LEDC_HIGH_SPEED_MODE, LEDC_CHANNEL_1, SOL2_DUTY_OFF);
    ledc_update_duty(LEDC_HIGH_SPEED_MODE, LEDC_CHANNEL_1);
}

camera_state_t camera_state = {
    .if_display = false,
    .metering = {
        .last_lux = 0.0f,
        .auto_shutter_pos = 5,  // 1/2s，安全起步
    },
    .button = {
        .available = false,
        .old_value = "111",
        .debounce_last = 0,
        .push_down_start = 0,
    },
    .menu = MENU_AUTO,
    .cam_mode = "AUTO",
    .time_mode = 0,
    .shut_mode = '1',
    .shutter_speed = 4,  // 1s
    .test_led_level = false,
    .has_flash = false,
    .self_timer_sec = 0,
    .multi_exp_remain = 0
};

// 根据校准后 EV 计算快门速度 (F/8 镜头，标称快门)
//
// 原理: EV = log₂(F² / t) = log₂(64 / t_nominal)
// 阈值取相邻两档 EV 的中点
// 注: shutter_times_x10[] 为校准后实际延时，与此表无关
//
//  索引 | 快门    | 标称 t   | EV    | 阈值 EV
//  ─────┼─────────┼──────────┼───────┼────────
//   0   | 3s      | 3.0      |  4.42 | ≤4.55
//   1   | 2.5s    | 2.5      |  4.68 | ≤4.84
//   2   | 2s      | 2.0      |  5.00 | ≤5.21
//   3   | 1.5s    | 1.5      |  5.42 | ≤5.71
//   4   | 1s      | 1.0      |  6.00 | ≤6.50
//   5   | 1/2     | 0.5      |  7.00 | ≤7.29
//   6   | 1/3     | 0.333    |  7.58 | ≤7.79
//   7   | 1/4     | 0.25     |  8.00 | ≤8.29
//   8   | 1/6     | 0.167    |  8.58 | ≤8.79
//   9   | 1/8     | 0.125    |  9.00 | ≤9.16
//  10   | 1/10    | 0.1      |  9.32 | ≤9.62
//  11   | 1/15    | 0.0667   |  9.91 | ≤10.12
//  12   | 1/20    | 0.05     | 10.32 | ≤10.62
//  13   | 1/30    | 0.0333   | 10.91 | ≤11.20
//  14   | 1/45    | 0.0222   | 11.49 | ≤11.70
//  15   | 1/60    | 0.0167   | 11.91 | ≤12.20
//  16   | 1/90    | 0.0111   | 12.49 | ≤12.73
//  17   | 1/125   | 0.008    | 12.96 | ≤13.23
//  18   | 1/180   | 0.00556  | 13.49 | ≤13.73
//  19   | 1/250   | 0.004    | 13.96 | ≤14.23
//  20   | 1/360   | 0.00278  | 14.49 | ≤14.73
//  21   | 1/500   | 0.002    | 14.96 | ≤15.46
//  22   | 1/1000  | 0.001    | 15.96 | ≤16.46
//  23   | 1/2000  | 0.0005   | 16.96 | ≤17.46
//  24   | 1/4000A | 0.00025  | 17.96 | ≤18.46
//  25   | 1/4000B | 0.00025  | 17.96 | (手动)
//  26   | 1/8000  | 0.000125 | 18.96 | ——
//
// 返回快门速度索引 (0-26)
uint8_t calc_shutter_from_ev(float ev)
{
    if (ev <= 4.55f) return 0;   // 3s
    if (ev <= 4.84f) return 1;   // 2.5s
    if (ev <= 5.21f) return 2;   // 2s
    if (ev <= 5.71f) return 3;   // 1.5s
    if (ev <= 6.50f) return 4;   // 1s
    if (ev <= 7.29f) return 5;   // 1/2
    if (ev <= 7.79f) return 6;   // 1/3
    if (ev <= 8.29f) return 7;   // 1/4
    if (ev <= 8.79f) return 8;   // 1/6
    if (ev <= 9.16f) return 9;   // 1/8
    if (ev <= 9.62f) return 10;  // 1/10
    if (ev <= 10.12f) return 11; // 1/15
    if (ev <= 10.62f) return 12; // 1/20
    if (ev <= 11.20f) return 13; // 1/30
    if (ev <= 11.70f) return 14; // 1/45
    if (ev <= 12.20f) return 15; // 1/60
    if (ev <= 12.73f) return 16; // 1/90
    if (ev <= 13.23f) return 17; // 1/125
    if (ev <= 13.73f) return 18; // 1/180
    if (ev <= 14.23f) return 19; // 1/250
    if (ev <= 14.73f) return 20; // 1/360
    if (ev <= 15.46f) return 21; // 1/500
    if (ev <= 16.46f) return 22; // 1/1000
    if (ev <= 17.46f) return 23; // 1/2000
    if (ev <= 18.46f) return 24; // 1/4000A
    return 26;                    // 1/8000
}


/* ---- 显示任务（中优先级，200ms 周期，与按键/快门解耦） ---- */
static void display_task(void *pvParameters)
{
    while (1) {
        display_show_frame(&camera_state, &display);
        vTaskDelay(pdMS_TO_TICKS(200));
    }
}

/* ---- 测光任务（低优先级，1s 周期） ---- */
static void metering_task(void *pvParameters)
{
    esp_err_t ret = opt4001_init();
    if (ret != ESP_OK) {
        ESP_LOGE(TAG, "OPT4001 init failed: %s", esp_err_to_name(ret));
        vTaskDelete(NULL);
        return;
    }
    ESP_LOGI(TAG, "OPT4001 sensor initialized");

    static int opt_log_cnt = 0;
    while (1) {
        float lux;
        if (opt4001_read_lux(&lux) == ESP_OK) {
            camera_state.metering.last_lux_raw = lux;
            camera_state.metering.ev_raw = log2f(lux * 2.56f);  // 原始 EV
            lux *= METERING_ATTEN_K;          // 窗口衰减校准
            camera_state.metering.last_lux = lux;
            camera_state.metering.ev = log2f(lux * 2.56f);  // 校准后 EV
            camera_state.metering.auto_shutter_pos = calc_shutter_from_ev(camera_state.metering.ev);

            if (++opt_log_cnt % 5 == 0) {
                ESP_LOGI(TAG, "OPT4001: raw=%.1f cal=%.1f EV=%.1f, shutter=%s",
                        camera_state.metering.last_lux_raw, lux, camera_state.metering.ev,
                        get_shutter_speed(camera_state.metering.auto_shutter_pos));
            }
        }
        vTaskDelay(pdMS_TO_TICKS(1000));
    }
}

static void suspend_noshut_task()
{
    if (control_task_handle) vTaskSuspend(control_task_handle);
    if (display_task_handle) vTaskSuspend(display_task_handle);
    if (metering_task_handle) vTaskSuspend(metering_task_handle);
}

static void resums_noshut_task()
{
    if (metering_task_handle) vTaskResume(metering_task_handle);
    if (display_task_handle) vTaskResume(display_task_handle);
    if (control_task_handle) vTaskResume(control_task_handle);
}

// 单次曝光（步骤 3~6）：Y Delay → 自拍倒计时 → 曝光 → 关快门 → 光圈归位
// 用于多重曝光时重复调用，不包含电机动作和吐片
static void single_shut(char mode, bool use_flash, uint16_t shutter_delay_x10)
{
        // ---- 3. Y Delay ----
        if (camera_state.self_timer_sec > 0) {
            suspend_noshut_task();
            for (int remain = camera_state.self_timer_sec; remain > 0; remain--) {
                display_show_countdown(&display, (int16_t)remain);
                delay_us(1000000);
            }
            resums_noshut_task();
        }

        if (use_flash) {  // SHUTTER_FLASH
            sol2_engage();
            ESP_LOGI(TAG, "Aperture engaged");
        }
        delay_us(18000);  // 18ms Y delay

        // ---- 4. 曝光 ----
        ESP_LOGI(TAG, "Exposure: mode=%c, delay=%d (0.1ms)", mode, shutter_delay_x10);
        suspend_noshut_task();

        if (mode == '1') {  // SHUTTER_NORMAL
            if(!use_flash){
                sol1_release();                               // shutter_open
                delay_us((uint32_t)shutter_delay_x10 * 100);  // 0.1ms → us
                // sol1_pull();                                  // 100% 吸合
            }
            else{
                int gap = (int)shutter_delay_x10 - 470;
                if (gap < 0) gap = 0;

                sol1_release();               // shutter_open
                delay_us(47000);              // 47ms

                gpio_set_level(FF_PIN, 1);     // 触发闪光灯
                delay_us(1000);                // 1ms
                gpio_set_level(FF_PIN, 0);
                delay_us((uint32_t)gap * 100); // 剩余延时

                // sol1_pull();                  // 100% 吸合
            }
            // delay_us(30000);                               // 30ms
            // sol1_hold();                                  // 40% 保持
        } else if (mode == 'B') {  // SHUTTER_BULB
            sol1_release();               // shutter_open
            delay_us(15000);              // 15ms

            if (use_flash){
                delay_us(32000);
                gpio_set_level(FF_PIN, 1);     // 触发闪光灯
                delay_us(1000);                // 1ms
                gpio_set_level(FF_PIN, 0);
            }

            // 等待 S1T 释放（正计时显示）
            int64_t start = esp_timer_get_time();
            uint32_t last_s = UINT32_MAX;
            while (gpio_get_level(S1T_PIN) == 0) {
                uint32_t cur_s = (esp_timer_get_time() - start) / 1000000;
                if (cur_s != last_s) {
                    last_s = cur_s;
                    display_show_countdown(&display, (int16_t)cur_s);
                }
                vTaskDelay(pdMS_TO_TICKS(1));
            }

        } else if (mode == 'T') {  // SHUTTER_TIME
            sol1_release();               // shutter_open

            if (use_flash){
                delay_us(47000);
                gpio_set_level(FF_PIN, 1);     // 触发闪光灯
                delay_us(1000);                // 1ms
                gpio_set_level(FF_PIN, 0);
            }

            // 等待 S1T 释放
            while (gpio_get_level(S1T_PIN) == 0) {
                delay_us(100);
            }
            // 等待 S1T 再次按下 或 定时超时
            {
                int64_t start = esp_timer_get_time();
                uint64_t target = (camera_state.time_mode > 1)
                    ? (uint64_t)camera_state.time_mode * 1000000ULL
                    : UINT64_MAX;
                bool is_countdown = (target != UINT64_MAX);
                uint32_t last_s = UINT32_MAX;

                while (esp_timer_get_time() - start < target &&
                        gpio_get_level(S1T_PIN) != 0) {
                    int64_t elapsed = esp_timer_get_time() - start;
                    uint32_t cur_s = is_countdown
                        ? (target - elapsed) / 1000000
                        : elapsed / 1000000;

                    if (cur_s != last_s) {
                        last_s = cur_s;
                        display_show_countdown(&display, (int16_t)cur_s);
                    }
                    delay_us(1000);
                }
            }
            
        }
        resums_noshut_task();

        // ---- 5. 关闭快门，曝光结束 ----
        sol1_pull();                    // 100% 吸合
        ESP_LOGD(TAG, "Shutter closing");
        delay_us(30000);                // 30ms
        sol1_hold();                    // 40% 保持
        delay_us(18000);                // 18ms

        // ---- 6. 光圈归位 ----
        if (use_flash) {  // SHUTTER_FLASH
            sol2_disengage();
            ESP_LOGI(TAG, "Aperture disengaged");
        }

        while (gpio_get_level(S1T_PIN) == 0) { delay_us(100); }
}

/* ---- 快门任务（移植 SX70Mk2 shutter_expose 完整时序） ---- */
static void shutter_task(void *pvParameters)
{
    while (1) {
        ulTaskNotifyTake(pdTRUE, portMAX_DELAY);    // 等待曝光开始

        ESP_LOGI(TAG, "Taking picture...");

        // 检查是否在拍摄模式（menu 10 = 自拍定时）
        if (camera_state.menu >= MENU_SETTINGS_START) {
            ESP_LOGI(TAG, "Not in shooting mode (Manuel)");
            continue;
        }

#if HAS_FOCUS
        if (!camera_state.if_focused) {
            do_focus(&camera_state.shut_mode, &camera_state.shutter_speed);
        }
#else
        // TODO: 对焦功能待实现（需移植 do_focus / S1F_FBW_PIN）
#endif

        uint16_t shutter_delay_x10 = get_shutter_time_x10(camera_state.shutter_speed);
        char mode = camera_state.shut_mode;
        bool use_flash = camera_state.has_flash;

        // 关闭 LED
        gpio_set_level(LED1_PIN, 1);

        // ---- 1. 关闭快门 ----
        ESP_LOGD(TAG, "Shutter close");
        sol1_pull();                    // 100% 吸合
        delay_us(30000);                // 30ms
        sol1_hold();                    // 40% 保持
        ESP_LOGD(TAG, "Shutter closed");

        // ---- 2. 电机启动，反光板上升 ----
        gpio_set_level(MOTOR_PIN, 1);
        ESP_LOGI(TAG, "Motor start (mirror up)");

        // 等待反光板就位 (S3 变高, 5×7µs 防抖)
        while (!gpio_debounce_defaultLow(S3_PIN)) {
            delay_us(100);
        }
        gpio_set_level(MOTOR_PIN, 0);
        ESP_LOGI(TAG, "Motor stopped");

        // 多重曝光：先拍第一张，再等 S1T 拍后续
        //   multi_exp_remain =  0 → 1 次正常曝光
        //   multi_exp_remain =  N → 1 + N 次曝光（每次 S1T 触发）
        //   multi_exp_remain = -1 → 同 0（仅 while 循环内检测用于中途中止）
        single_shut(mode, use_flash, shutter_delay_x10);

        while (camera_state.multi_exp_remain > 0) {
            camera_state.multi_exp_remain--;
            ulTaskNotifyTake(pdTRUE, portMAX_DELAY);
            if (camera_state.multi_exp_remain == -1) break;
            shutter_delay_x10 = get_shutter_time_x10(camera_state.shutter_speed);
            mode = camera_state.shut_mode;
            use_flash = camera_state.has_flash;
            single_shut(mode, use_flash, shutter_delay_x10);
        }

        // ---- 7. 电机启动吐片 ----
        gpio_set_level(MOTOR_PIN, 1);
        ESP_LOGI(TAG, "Motor start (film ejection)");

        // 等待 S5 变低（胶片检测, 5×7µs 防抖）
        while (gpio_debounce_defaultHigh(S5_PIN)) {
            delay_us(100);
        }

        gpio_set_level(MOTOR_PIN, 0);
        sol1_release();               // shutter_open
        ESP_LOGI(TAG, "Film ejection complete");

        // ---- 8. 等待 S1T 释放，防止连拍 ----
        while (gpio_get_level(S1T_PIN) == 0) {
            delay_us(10000);  // 10ms
        }
    }
}

void control_task(void *pvParameters)
{
    /* ---- SSD1306 OLED（I2C1, 0x3C, 128x64） ---- */
    if (ssd1306_init(&display, 128, 32, 0x3C, I2C_NUM_1, false)) {
        ssd1306_clear(&display);
        ssd1306_draw_str(&display, 0, 0, "SX70z Ready", &font5x8_font);
        ssd1306_show(&display);
        camera_state.if_display = true;
        ESP_LOGI(TAG, "SSD1306 initialized");
        /* ---- 启动显示任务（Core 1，中优先级） ---- */
        xTaskCreatePinnedToCore(display_task, "display", 2048, NULL,
                                DISPLAY_TASK_PRIO, &display_task_handle, 1);
    } else {
        ESP_LOGE(TAG, "SSD1306 init failed");
    }

    /* ---- PCF8575 GPIO 扩展（I2C1, 0x20） ---- */
    if (pcf8575_init(&gpio_expander, I2C_NUM_1, 0x20, 0xFFFF) == 0) {
        ESP_LOGI(TAG, "PCF8575 initialized");
        camera_state.button.available = true;
    } else {
        ESP_LOGE(TAG, "PCF8575 init failed");
        camera_state.button.available = false;
    }

    /* ---- 启动测光任务（Core 1，低优先级） ---- */
    xTaskCreatePinnedToCore(metering_task, "metering", 2048, NULL,
                            METERING_TASK_PRIO, &metering_task_handle, 1);

    /* ---- 初始化 us 级精确定时器（GPTimer，ISR 绑定 Core 1） ---- */
    gptimer_config_t tcfg = {
        .clk_src = GPTIMER_CLK_SRC_DEFAULT,
        .direction = GPTIMER_COUNT_UP,
        .resolution_hz = 1000000,  // 1MHz → 1μs
        .intr_priority = 1,
    };
    gptimer_new_timer(&tcfg, &g_delay_timer);

    gptimer_event_callbacks_t cbs = {
        .on_alarm = delay_timer_cb,
    };
    gptimer_register_event_callbacks(g_delay_timer, &cbs, NULL);
    gptimer_enable(g_delay_timer);

    /* ---- 初始化 LEDC PWM（SOL1: 快门电磁铁, SOL2: 光圈电磁铁, 8-bit 31.25kHz） ---- */
    ledc_timer_config_t ledc_timer = {
        .speed_mode = LEDC_HIGH_SPEED_MODE,
        .duty_resolution = LEDC_TIMER_8_BIT,
        .timer_num = LEDC_TIMER_0,
        .freq_hz = 31250,
        .clk_cfg = LEDC_AUTO_CLK,
    };
    ledc_timer_config(&ledc_timer);

    ledc_channel_config_t sol1_ch = {
        .gpio_num   = SOL1_PIN,
        .speed_mode = LEDC_HIGH_SPEED_MODE,
        .channel    = LEDC_CHANNEL_0,
        .timer_sel  = LEDC_TIMER_0,
        .duty       = 0,
        .hpoint     = 0,
    };
    ledc_channel_config(&sol1_ch);

    ledc_channel_config_t sol2_ch = {
        .gpio_num   = SOL2_PIN,
        .speed_mode = LEDC_HIGH_SPEED_MODE,
        .channel    = LEDC_CHANNEL_1,
        .timer_sel  = LEDC_TIMER_0,
        .duty       = 0,
        .hpoint     = 0,
    };
    ledc_channel_config(&sol2_ch);
    ESP_LOGI(TAG, "LEDC PWM initialized (31.25kHz, 8-bit)");

    /* ---- 启动快门任务（Core 1，最高优先级，平时阻塞） ---- */
    xTaskCreatePinnedToCore(shutter_task, "shutter", 2048, NULL,
                            SHUTTER_TASK_PRIO, &shutter_task_handle, 1);

    while (1) {
        // 3D 按键处理
        button3d_handler();
        update_mode_display();

        // 闪光灯检测
        camera_state.has_flash = gpio_inputs_read_s2();

        // S1 去抖读取
        bool s1t_pressed = debounce_read_s1pin();

        // S1T 全按快门 → 触发快门任务（参考 if s1t_pressed == 1）
        if (! s1t_pressed) {
            if (camera_state.menu < MENU_SETTINGS_START) {
                // AUTO 模式：自动选择测光计算的快门速度
                if (camera_state.menu == MENU_AUTO) {
                    camera_state.shutter_speed = camera_state.metering.auto_shutter_pos;
                    // 闪光灯同步：有闪光灯时固定 1/30s
                    if (camera_state.has_flash) {
                        camera_state.shutter_speed = 13;  // 1/30s
                    }
                }
                xTaskNotifyGive(shutter_task_handle);
            }
        }

        static int ctrl_log_cnt = 0;
        if (++ctrl_log_cnt % 16 == 0) {
            ESP_LOGI(TAG, "S1T=%d Flash=%d Mode=%s LUX=%.2f",
                    s1t_pressed, camera_state.has_flash,
                    camera_state.cam_mode, camera_state.metering.last_lux);
        }

        // 无屏幕时 LED 心跳指示，有屏幕则保持熄灭
        if (!camera_state.if_display) {
            camera_state.test_led_level = !camera_state.test_led_level;
            gpio_set_level(LED1_PIN, camera_state.test_led_level);
        } else {
            gpio_set_level(LED1_PIN, 1);  // LED 低电平点亮，1=灭
        }
        vTaskDelay(pdMS_TO_TICKS(30));
    }
}

void camera_pause(void)
{
    if (control_task_handle) {
        vTaskSuspend(control_task_handle);
        // 等待 Core 1 任务真正挂起后才返回
        while (eTaskGetState(control_task_handle) != eSuspended) {
            vTaskDelay(pdMS_TO_TICKS(10));
        }
        ESP_LOGI(TAG, "Paused for OTA");
    }
}

void camera_resume(void)
{
    if (control_task_handle) {
        vTaskResume(control_task_handle);
        ESP_LOGI(TAG, "Resumed after OTA");
    }
}

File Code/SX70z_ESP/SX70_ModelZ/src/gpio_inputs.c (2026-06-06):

/* gpio_inputs.c - GPIO 输入处理：S1/S2 去抖、3D 按键、菜单/模式切换 */

#include "gpio_inputs.h"
#include "camera_main.h"
#include "pcf8575.h"
#include "PIN.h"
#include "driver/gpio.h"
#include <stdio.h>
#include <string.h>

extern pcf8575_t gpio_expander;

/* ---- GPIO 防抖 ---- */

bool gpio_debounce_defaultLow(int pin) {
    for (int i = 0; i < GPIO_DEBOUNCE_COUNT; i++) {
        if (!gpio_get_level(pin)) return false;
        delay_us(7);
    }
    return true;
}

bool gpio_debounce_defaultHigh(int pin) {
    for (int i = 0; i < GPIO_DEBOUNCE_COUNT; i++) {
        if (gpio_get_level(pin)) return true;
        delay_us(7);
    }
    return false;
}

/* ---- S1 按键去抖 ---- */
static uint8_t s1f = 0;
static uint8_t s1t = 0;

bool debounce_read_s1pin(void)
{
    if (gpio_get_level(S1T_PIN) == 0) {
        s1t = (s1t == 0) ? s1t : s1t - 1;
    } else {
        s1t = S1_DEBOUNCE_COUNT;
    }
    // S1F 半按对焦——当前硬件可能没有，预留
    return s1t > 0;
}

/* ---- S2 闪光灯检测 ---- */
bool gpio_inputs_read_s2(void)
{
    static int flash_debounce = 0;
    bool flash_level = (gpio_get_level(S2_PIN) == 0);
    if (flash_level) {
        flash_debounce = (flash_debounce < 10) ? flash_debounce + 1 : 10;
    } else {
        flash_debounce = (flash_debounce > 0) ? flash_debounce - 1 : 0;
    }
    return flash_debounce >= 8;
}

/* ---- 3D 按键处理（移植自 SX70Mk2 主循环 button3d_handler） ---- */

// 自拍定时选项：0/2/5/10s
static const uint8_t self_timer_opts[] = {0, 2, 5, 10};

// 多重曝光选项（-1=中止, 0=正常, 1~10=额外张数）
static const int8_t multi_exp_opts[] = {-1, 0, 1, 2, 3, 4, 5, 6, 7, 8, 9, 10};
#define MULTI_EXP_OPTS_COUNT 12

// 菜单参数项
typedef struct {
    const char *name;         // 显示名称
    uint8_t opts_count;       // 选项个数（0=只读，不响应调整）
    const int8_t *opts;       // 可选值表（NULL=只读）
    int8_t *value;            // 指向 camera_state 字段（只读项可为 NULL）
} menu_item_t;

static const menu_item_t menu_items[] = {
    {"SelfTimer", SELF_TIMER_OPTS_COUNT, (const int8_t *)self_timer_opts, (int8_t *)&camera_state.self_timer_sec},
    {"MultiExp",  MULTI_EXP_OPTS_COUNT,   multi_exp_opts,                &camera_state.multi_exp_remain},
    {"IP Addr",   0,                       NULL,                          NULL},
};
#define MENU_ITEM_COUNT 3

int8_t menu_item_idx = 0;   // 当前选中的参数索引
bool menu_adjust = false;    // true=正在调值


// 读取 PCF8575 按键状态 -> "101" 格式（1=未按下，0=按下）
static void read_3d_button_pins(char *result)
{
    if (!camera_state.button.available) {
        result[0] = '1'; result[1] = '1'; result[2] = '1'; result[3] = '\0';
        return;
    }
    uint16_t state = pcf8575_read(&gpio_expander);

    result[0] = ((state >> PCF_BUTTON3D_DOWN) & 1) ? '1' : '0';
    result[1] = ((state >> PCF_BUTTON3D_UP) & 1) ? '1' : '0';
    result[2] = ((state >> PCF_BUTTON3D_PUSH) & 1) ? '1' : '0';
    result[3] = '\0';
}

// 更新 cam_mode 字符串 + shut_mode
void update_mode_display(void)
{
    if (camera_state.menu == MENU_AUTO) {
        snprintf(camera_state.cam_mode, sizeof(camera_state.cam_mode), "AUTO");
        camera_state.shut_mode = '1';
    } else if (camera_state.menu == MENU_BULB) {
        // menu 1: B/T 合并，通过 time_mode 区分
        if (camera_state.time_mode == 0) {
            snprintf(camera_state.cam_mode, sizeof(camera_state.cam_mode), "B");
            camera_state.shut_mode = 'B';
        } else if (camera_state.time_mode == 1) {
            snprintf(camera_state.cam_mode, sizeof(camera_state.cam_mode), "T");
            camera_state.shut_mode = 'T';
        } else {
            // time_mode >= 2: 秒值延时，暂用 T 标记
            snprintf(camera_state.cam_mode, sizeof(camera_state.cam_mode),
                    "%us", camera_state.time_mode);
            camera_state.shut_mode = 'T';
        }
    } else if (camera_state.menu == MENU_MANUAL) {
        snprintf(camera_state.cam_mode, sizeof(camera_state.cam_mode), "%s",
                get_shutter_speed(camera_state.shutter_speed));
        camera_state.shut_mode = '1';
    } else if (camera_state.menu == MENU_SELF_TIMER) {
        snprintf(camera_state.cam_mode, sizeof(camera_state.cam_mode), "Menu 0");
    }
}

// 下键按下

// time_mode 步进（上键方向）：0→1, ≤10→+1, ≤60→+5, ≤600→+30, ≤1800→+60,
// ≤3600→+5min, ≤7200→+10min, 之后→+30min
static uint16_t time_mode_next(uint16_t cur)
{
    uint16_t step;
    if (cur < 10)   step = 1;
    else if (cur < 60)   step = 5;
    else if (cur < 600)  step = 30;
    else if (cur < 1800) step = 60;
    else if (cur < 3600) step = 300;
    else if (cur < 7200) step = 600;
    else step = 1800;

    uint16_t next = cur + step;
    if (next > 18000) return 0;  // 5h 上限，超过回绕到 0
    return next;
}

// time_mode 步进（下键方向，反向）
static uint16_t time_mode_prev(uint16_t cur)
{
    if (cur <= 0)   return 0;
    if (cur == 1)   return 0;
    if (cur <= 10)  return cur - 1;
    if (cur <= 60)  return cur - 5;
    if (cur <= 600) return cur - 30;
    if (cur <= 1800) return cur - 60;
    if (cur <= 3600) return cur - 300;
    if (cur <= 7200) return cur - 600;
    return cur - 1800;
}
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

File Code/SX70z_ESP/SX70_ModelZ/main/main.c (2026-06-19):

/**
 * SX70_ModelZ — 主程序
 *
 * CPU 分配：
 *   Core 0: WiFi 协议栈 + NimBLE BLE + 事件处理（射频相关，必须在此核）
 *   Core 1: 相机控制任务（时序敏感，与射频中断隔离）
 *
 * 初始化流程（均在 Core 0 顺序执行）：
 *   0. devinfo_init()          — 芯片 MAC → 设备序列号
 *   1. OTA 回滚检查             — 若分区为 PENDING_VERIFY，立即确认固件有效
 *   2. pin_init()              — GPIO 初始化
 *   3. NVS 初始化               — 存储 WiFi 凭据、BLE 配对信息
 *   4. 网络栈 (netif + event loop)
 *   5. 注册 WiFi/IP/Provisioning 事件回调
 *   6. WiFi STA 启动            — Station 模式，设置主机名 "SX70z"
 *   7. BLE Provisioning         — 未配网则广播，已配网则直接连 WiFi
 *   8. 启动控制任务到 Core 1     — 独立运行，不受 WiFi/BLE 状态影响
 *   9. Idle 循环 (RSSI 监控)    — Core 0 空闲，打印 WiFi 信号强度
 */

#include <stdio.h>
#include "freertos/FreeRTOS.h"
#include "freertos/task.h"
#include "esp_log.h"
#include "nvs_flash.h"
#include "esp_netif.h"
#include "esp_wifi.h"
#include "esp_event.h"
#include "wifi_provisioning/manager.h"
#include "wifi_provisioning/scheme_ble.h"
#include "devinfo.h"
#include "camera_main.h"
#include "shutter_cal.h"
#include "esp_ota_ops.h"
#include "ota_web.h"
#include "pin_init.h"

static const char *TAG = "main";

/* ================================================================
 *  WiFi 事件回调
 *
 *  由 ESP WiFi 任务调用，不占用 app_main 时间片。
 *  断线自动重连。
 * ================================================================ */

static void wifi_event_handler(void *arg, esp_event_base_t event_base,
                               int32_t event_id, void *event_data)
{
    if (event_base == WIFI_EVENT && event_id == WIFI_EVENT_STA_START) {
        ESP_LOGD(TAG, "WiFi STA started");
    } else if (event_base == WIFI_EVENT && event_id == WIFI_EVENT_STA_DISCONNECTED) {
        // 断线自动重连，不阻塞主程序
        ESP_LOGI(TAG, "WiFi disconnected, reconnecting...");
        camera_state.ip_str[0] = '\0';
        esp_wifi_connect();
    } else if (event_base == IP_EVENT && event_id == IP_EVENT_STA_GOT_IP) {
        ip_event_got_ip_t *ev = (ip_event_got_ip_t *)event_data;
        ESP_LOGI(TAG, "WiFi connected, IP: " IPSTR, IP2STR(&ev->ip_info.ip));
        snprintf(camera_state.ip_str, sizeof(camera_state.ip_str),
                 IPSTR, IP2STR(&ev->ip_info.ip));
        static bool ota_started = false;
        if (!ota_started) {
            ota_started = true;
            ota_web_start();
        }
    }
}

/* ================================================================
 *  Provisioning 事件回调
 *
 *  BLE 配网流程的状态通知，仅做日志记录。
 *  配网失败时重启让用户重试。
 * ================================================================ */

static void prov_event_handler(void *arg, esp_event_base_t event_base,
                               int32_t event_id, void *event_data)
{
    if (event_base != WIFI_PROV_EVENT) return;

    switch (event_id) {
    case WIFI_PROV_START:
        ESP_LOGD(TAG, "Provisioning started");
        break;
    case WIFI_PROV_CRED_RECV:
        // 手机 App 已发送 WiFi 凭据
        ESP_LOGD(TAG, "WiFi credentials received");
        break;
    case WIFI_PROV_CRED_SUCCESS:
        // 凭据正确，WiFi 已连接
        ESP_LOGI(TAG, "Provisioning successful");
        break;
    case WIFI_PROV_CRED_FAIL:
        ESP_LOGI(TAG, "Provisioning failed, restarting...");
        esp_restart();
        break;
    case WIFI_PROV_END:
        // 配网流程结束（BLE 保持广播，不受影响）
        ESP_LOGD(TAG, "Provisioning ended");
        break;
    default:
        break;
    }
}

/* ================================================================
 *  app_main — 入口
 *
 *  所有初始化均为非阻塞调用，完成后进入主控循环。
 *  WiFi 配网、BLE 连接均在后台由各自的 FreeRTOS 任务处理。
 * ================================================================ */

void app_main(void)
{
    /* ---- 0. 确认当前芯片序列号 ---- */
    devinfo_init();

    /* ---- 1. OTA 回滚检查 ---- */
    const esp_partition_t *running = esp_ota_get_running_partition();
    esp_ota_img_states_t ota_state;
    if (esp_ota_get_state_partition(running, &ota_state) == ESP_OK) {
        ESP_LOGI(TAG, "Running partition: %s, state: %d",
                running->label, ota_state);
        if (ota_state == ESP_OTA_IMG_PENDING_VERIFY) {
            ESP_LOGI(TAG, "OTA boot confirmed, marking app as valid");
            esp_ota_mark_app_valid_cancel_rollback();
        } else if (ota_state == ESP_OTA_IMG_VALID) {
            ESP_LOGD(TAG, "App already confirmed");
        } else if (ota_state == ESP_OTA_IMG_NEW) {
            ESP_LOGI(TAG, "New app, marking as valid");
            esp_ota_mark_app_valid_cancel_rollback();
        }
    } else {
        ESP_LOGW(TAG, "Cannot read OTA state, partition table may be invalid");
    }

    /* ---- 2. 引脚初始化 ---- */
    pin_init();
    ESP_LOGI(TAG, "SX70z starting...");
    ESP_LOGI(TAG, "Model: %s  SN: %s  SW: %d.%d.%d  HW: r%d",
            device.model, device.serial,
            device.sw_major, device.sw_minor, device.sw_patch,
            device.hw_rev);


    /* ---- 3. NVS 初始化 ---- */
    esp_err_t ret = nvs_flash_init();
    if (ret == ESP_ERR_NVS_NO_FREE_PAGES || ret == ESP_ERR_NVS_NEW_VERSION_FOUND) {
        ESP_ERROR_CHECK(nvs_flash_erase());
        ret = nvs_flash_init();
    }
    ESP_ERROR_CHECK(ret);

    /* ---- 3.5 加载快门校准值 ---- */
    ESP_ERROR_CHECK(shutter_cal_init());

    /* ---- 4. 网络栈初始化 ---- */
    ESP_ERROR_CHECK(esp_netif_init());
    ESP_ERROR_CHECK(esp_event_loop_create_default());

    /* ---- 5. 注册事件回调 ---- */
    ESP_ERROR_CHECK(esp_event_handler_register(WIFI_EVENT, ESP_EVENT_ANY_ID,
                                                wifi_event_handler, NULL));
    ESP_ERROR_CHECK(esp_event_handler_register(IP_EVENT, IP_EVENT_STA_GOT_IP,
                                                wifi_event_handler, NULL));
    ESP_ERROR_CHECK(esp_event_handler_register(WIFI_PROV_EVENT, ESP_EVENT_ANY_ID,
                                                prov_event_handler, NULL));

    /* ---- 6. WiFi STA 启动 ---- */
    esp_netif_t *sta_netif = esp_netif_create_default_wifi_sta();
    esp_netif_set_hostname(sta_netif, "SX70z");
    wifi_init_config_t cfg = WIFI_INIT_CONFIG_DEFAULT();
    ESP_ERROR_CHECK(esp_wifi_init(&cfg));
    ESP_ERROR_CHECK(esp_wifi_set_mode(WIFI_MODE_STA));
    ESP_ERROR_CHECK(esp_wifi_start());

    /* ---- 7. BLE Provisioning ---- */
    wifi_prov_mgr_config_t prov_config = {
        .scheme = wifi_prov_scheme_ble,
        .scheme_event_handler = WIFI_PROV_SCHEME_BLE_EVENT_HANDLER_FREE_BTDM,
        .app_event_handler = WIFI_PROV_EVENT_HANDLER_NONE,
    };
    ESP_ERROR_CHECK(wifi_prov_mgr_init(prov_config));

    bool provisioned = false;
    wifi_prov_mgr_is_provisioned(&provisioned);

    if (!provisioned) {
        ESP_LOGI(TAG, "Not provisioned, starting BLE provisioning...");
        wifi_prov_security_t security = WIFI_PROV_SECURITY_1;
        ESP_ERROR_CHECK(wifi_prov_mgr_start_provisioning(
            security, "sx70z123", "SX70z_POP", NULL));
    } else {
        ESP_LOGI(TAG, "Already provisioned, connecting to WiFi...");
        wifi_prov_mgr_deinit();
        esp_wifi_connect();
    }
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

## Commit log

2026-05-23 Initial commit: SX70z firmware + hardware
    Software: GPLv3 Hardware: CERN-OHL-S 2.0
    [BOM_right.xlsx, BodyControllerForSX70z.kicad_pcb, BodyControllerForSX70z.kicad_sch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]
2026-05-31 camera: 显示独立为 Display Task，与按键控制解耦
    - 新增 display_task (prio 5, 200ms I2C 刷屏)
    - control_task 剥离显示逻辑，循环从 100ms 提速到 30ms
    - 按键响应不再被 SSD1306 I2C 传输阻塞
    - Core 1 任务从 3 个增至 4 个
2026-05-31 docs: 清理 CLAUDE.md 中的旧项目路径引用
2026-06-02 fix: B/T 模式 shut_mode 未根据 menu 设置导致快门走 normal 路径
    无闪光灯时 shut_mode 现在根据 menu 自动切换:
    menu=0/3 → '1' (normal), menu=1 → 'B', menu=2 → 'T'
    [camera_main.c]
2026-06-03 refactor: 闪光灯检测与拍摄模式分离
    - camera_state_t 新增 has_flash 字段，control_task 统一维护
    - update_mode_display() 同步设 shut_mode（menu 变化时自动映射）
    - 删除 control_task 中 flash_debounce 覆写 shut_mode 的耦合
    - AUTO 闪光灯同步改用 has_flash
    - display_manager.c 改用 state->has_flash，移除 PIN.h/gpio.h
    - shutter_task 曝光阶段合并普通/闪光子路径，共用第5步关快门
    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
2026-06-03 feat: 自拍定时设置功能
    menu=10 下通过上下键设置定时值（0/2/5/10s），shutter_task
    倒计时前挂起其他 Core 1 任务，每秒刷新 countdown 显示。
    - camera_state_t 新增 self_timer_sec 字段
    - up/down_button_call 增加 menu==10 分支
    - display_show_countdown 新函数
    - 快门速度行显示定时值（如 "1/125 5s"）
2026-06-03 docs: CLAUDE.md 重命名为 AGENTS.md，补充自拍定时文档
2026-06-03 fix: 自拍定时倒计时移至步骤3 Y Delay前
    避免倒计时期间快门未关闭导致漏光，同时反光板已预升
    无振动。TODO.md 清理已完成的闪光灯分离重构。
    [camera_main.c]
2026-06-03 拆分GPIO相关代码，未测试
2026-06-03 refactor: 拆分 gpio_inputs 模块 + 整理 #define 到头文件
    - 新建 gpio_inputs.c/h，搬入 GPIO 去抖、S1/S2 检测、3D 按键代码
    - debounce_read_s1pin 改为返回 bool
    - 新增 gpio_inputs_read_s2() 封装闪光灯检测
    - 所有 #define 移到对应头文件，c 文件内无宏定义
    - 各 c 文件开头添加功能描述注释
2026-06-03 docs: 更新自拍定时/闪光矩阵/软件架构说明
2026-06-03 docs: 更新 Readme — 配网/OTA/行为矩阵/测光标定/样片
2026-06-05 feat: 拆分 single_shut，添加多重曝光框架
    - 步骤 3~6 抽出为 single_shut()，供多重曝光重复调用
    - 新增 multi_exp_remain 字段（0=正常，N=追加N张，-1=立即吐片）
    - 多重曝光每张之间阻塞等 S1T，允许张间修改 shutter_speed/mode
2026-06-05 refactor: 简化多重曝光循环，去掉 while(true) 嵌套
    - single_shut 改为 static
    - multi_exp_remain=-1 不再跳过第一张，仅在 while 内用于中途中止
2026-06-06 refactor: 提取 display_show_taking，cam_mode 扩容，自拍菜单显示调整
    - display_show_taking() 接管拍摄模式数据绘制，布局代码保留在 frame()
    - cam_mode[8] → cam_mode[10]，适应菜单名称长度
    - 自拍菜单显示 "---" → "Menu 0"
    - shut_mode 注释清理（移除已废弃的闪灯模式）
    ⚠️ 未测试，需烧录验证
2026-06-06 build: 添加 sdkconfig.defaults，sdkconfig 回归 gitignore
    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
2026-06-06 refactor: display_manager 布局与内容分离，抽提 draw_str_taking
    - field[] 表统一管理坐标+字体，改布局只需改数组
    - draw_str_taking(disp, index, str) 按索引绘制，调用方只传内容
    - display_show_taking / display_show_menu 复用同一接口
    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
2026-06-06 更新了UI，T门B门菜单合并，T模式支持定时曝光
2026-06-06 feat: 设置菜单重构、菜单参数化、IP 显示、ssd1306_draw_str_black
    - 设置菜单（menu=10）改为参数驱动：SelfTimer / MultiExp / IP Addr
    - 上下键切换参数，短按进入调整，只读项不可调整
    - 多重曝光次数可在菜单中设置
    - IP 地址显示（WiFi GOT_IP 时写入 camera_state.ip_str）
    - 状态栏右上角显示自拍定时 + 多重曝光次数
    - ssd1306_draw_str_black() 移至 ssd1306 驱动层
    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
2026-06-07 fix: display_show_countdown int8_t→int16_t，修复 T门>127s 显示溢出
    [camera_main.c]
2026-06-07 docs: 更新 Readme — 多重曝光、设置菜单参数化、IP 显示
2026-06-07 更改Readmen
2026-06-19 feat: 快门校准值 NVS 持久化 + Web 编辑页面 (v1.5.1)
    - 新增 shutter_cal 模块：shutter_times_x10[] 从编译时常量改为 NVS 可写，
    magic 校验 (0x53583000|count) 保证固件升级自动失效回退默认值
    - 新增 GET/POST /calibration Web 端点：27 档校准值表格编辑、
    Save 持久化到 NVS、Reset 删除 key 恢复出厂默认
    - camera_main.c 移除静态快门表，改调 shutter_cal 模块 API
    - AGENTS.md 同步更新校准模块文档
    [camera_main.c, main.c]
2026-06-19 docs: 移除 http://SX70z 链接，改为相机 IP（无 mDNS 不可解析）
2026-06-24 feat: 飞行模式 — 菜单切换 + NVS 持久化 + OLED 飞机图标 [未测试]
    - 设置菜单新增 Flight 选项（ON/OFF），退出菜单时自动存 NVS 并重启
    - 开机检测飞行模式标志，跳过 WiFi/BLE/OTA 网络栈初始化
    - OLED 状态栏右上角显示 13x13 飞机位图
    - 新增 flight_cfg 模块（NVS namespace "cfg"）
    - NVS 宏名加模块前缀避免冲突（shutter_cal / flight_cfg）
2026-06-24 fix: 代码审查修复 — 类型安全 + 边界检查 + 飞机图标更新 [未验证]
    修复项:
    - self_timer_opts: uint8_t → int8_t 类型修复
    - ssd1306_draw_str_black: 添加字符范围检查
    - 菜单遍历: 添加 opts NULL 检查
    - 飞机图标: 更新为 plane.bmp (14x13)
    代码审查来源: CODE_ISSUES.md (已添加到 .gitignore)
2026-06-24 fix: 飞机图标改用 plane2.bmp 转换数据，修正位图尺寸 14x13
2026-06-24 release: 添加 v1.5.1 及 v1.6.1 构建产物
2026-11-05 完善复刻指南和硬件投产资料
2026-11-05 清理旧版主控工程及投产备份
